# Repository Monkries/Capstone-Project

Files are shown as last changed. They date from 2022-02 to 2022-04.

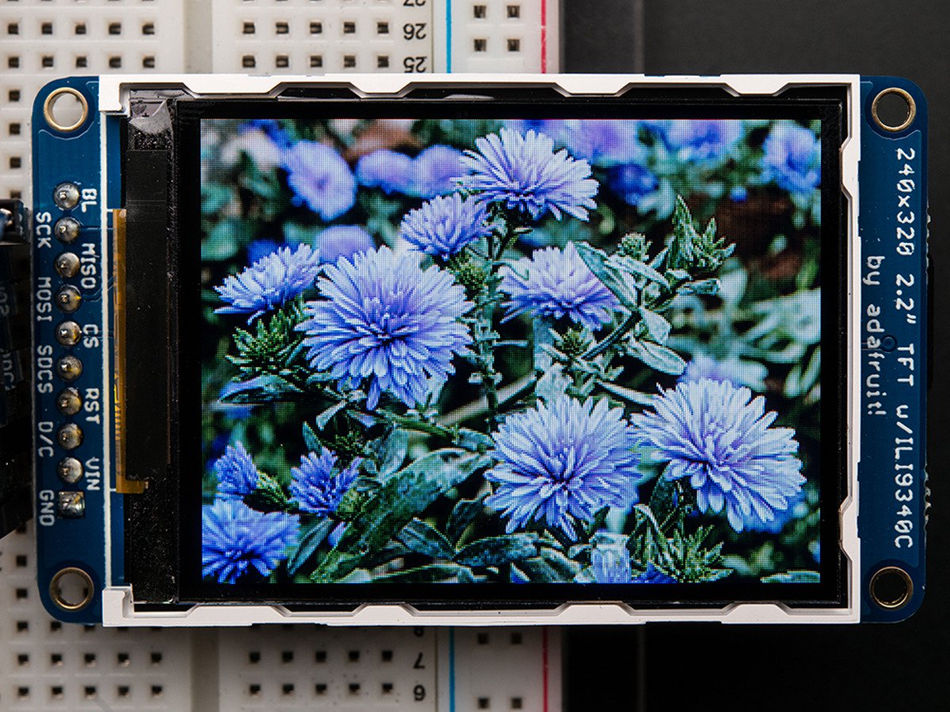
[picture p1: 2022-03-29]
Hardware/footprints/Adafruit-2.2-SPI-TFT-master/assets/image.jpg

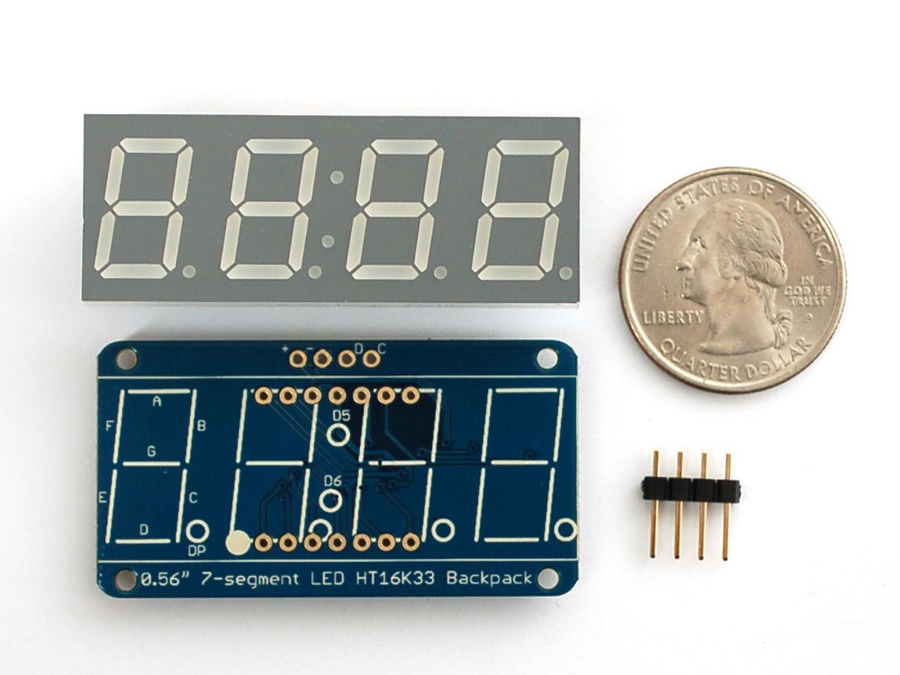
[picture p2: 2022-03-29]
Hardware/footprints/Adafruit-LED-Backpacks-master/assets/881.jpg

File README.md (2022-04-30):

# Capstone-Project
The lathe is arguably the most important machine tool in engineering history, and one of its defining features is the ability to cut threads. For hundreds of years, this has been accomplished by using gears to link the movement of the cutting tool to the movement of the spinning workpiece. To cut finer or coarser threads, the machinist must vary this gear ratio.This system works, but it has limitations. It is poorly suited for small benchtop machines, because the gearbox parts end up extremely small and expensive to manufacture. It is also inconvenient to adjust; the machinist must read a chart and physically add and remove gears from the geartrain. On larger lathes, this inconvenience is reduced using a simple transmission, allowing the machinist to shift several levers according to a chart, but this is more expensive, and more difficult to scale down to smaller machines.This project aims to replace this gearbox with electronics. This will eliminate the need to physically move gears around to adjust the system; instead, machinists will simply type in the desiredthread pitch into the control panel. Additionally, this system will be much more cost-effective and accessible on small benchtop lathes, where the traditional gearbox approach is impractical.

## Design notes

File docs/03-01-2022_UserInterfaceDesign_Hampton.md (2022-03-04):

### Layout

This is just a rough layout, not to scale, and not accounting for font size.

To the left, I've indicated the physical device that corresponds to each area of the screen.

```
{MODE NAME}      | 
                 |
{FEED or PITCH}  | --- Encoder
                 |
{UNITS TOGGLE}   | --- Button
{OTHER SETTING}  | --- Button
{OTHER SETTING}  | --- Button
```

### Mode 1: Threading

Example of cutting an English right-hand thread, with "Hardinge mode" (Rapid right) enabled
```
    THREADING    | 
                 |
      20TPI      | --- Encoder
                 |
      mm/in      | --- Button  (This changes the line above between TPI and mm, for inch or metric threads, respectively)
   RAPID RIGHT   | --- Button  (Options are RAPID RIGHT, RAPID LEFT, RAPID OFF)
                 | --- Button
```

Example of cutting a metric thread, with "Hardinge mode" disabled (no rapids in either direction)
```
    THREADING    | 
                 |
      1.75mm     | --- Encoder
                 |
      mm/in      | --- Button  (This changes the line above between TPI and mm, for inch or metric threads, respectively)
    RAPID OFF    | --- Button  (Options are RAPID RIGHT, RAPID LEFT, RAPID OFF)
                 | --- Button
```

### Mode 2: Power Feed

Example of power feed in inches per revolution
```
  Z POWER FEED   | 
                 |
   0.001"/REV    | --- Encoder
                 |
      mm/in      | --- Button  (This changes the line above between X"/REV and Xmm/REV)
                 | --- Button
                 | --- Button
```

Example of power feed in mm per revolution
```
  Z POWER FEED   | 
                 |
    0.2mm/REV    | --- Encoder
                 |
      mm/in      | --- Button  (This changes the line above between X"/REV and Xmm/REV)
                 | --- Button
                 | --- Button
```

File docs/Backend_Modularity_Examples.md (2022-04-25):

This example shows how the calls that might be made to take two passes on a 13TPI thread.

First we set up the gearbox, then engage the forward feed, allowing the cutter to make its first pass.

Then (whenever the cutter gets to the end of the part, probably triggered by a user input) we disengage the clutch, and engage the reverse feed.

After allowing the cutter to return to the right end of the part, we engage the forward feed again to begin another cutting pass. There's no need to worry about synchronization in software or with a threading dial, the software clutch model takes care of it.
```cpp
  // Example 1: Cutting a 13TPI thread
  els.gearbox.configuredPitch = {13, tpi, rightHandThread_feedLeft}; // Set desired thread pitch
  els.gearbox.enableMotorBraking = true;
  // Start feeding toward the headstock
  els.clutch.engageForward(); 
  // Then return to the start for another pass
  els.clutch.disengage();
  els.clutch.engageReverse();
  els.clutch.disengage();
  // Take another pass (the system will maintain sync automatically)
  els.clutch.engageForward();
 ```
 
 Another example: Configuring the gearbox for an inch power feed rate, feeding 0.005" per revolution of the spindle.
 ```cpp
 
  // Example 2: Power Feeding 0.005" per revolution towards the headstock
  els.gearbox.configuredPitch = {0.005, in_per_rev, rightHandThread_feedLeft};
  els.gearbox.enableMotorBraking = true;
  els.clutch.engageForward();
```

Another example: Configuring the gearbox for a metric thread, 1.75mm pitch.

```cpp

  // Example 3: Cutting a metric 1.75mm pitch thread
  els.gearbox.configuredPitch = {1.75, mm, rightHandThread_feedLeft};
  els.clutch.engageForward();
```

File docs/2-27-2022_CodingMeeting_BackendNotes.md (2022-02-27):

From meeting on 2-27 with Karson and Hampton

```c++

  // Scenario 1: Thread, Hardinge Mode, 1/2"-13
  // Step 1: gearbox setup (from control panel)
  ELS.configureGearing(13, "tpi");
  ELS.configureClutch(false, true, cfg_rapidStepRate);
  ELS.configureMotorBraking(true); // TODO: get from cpanel switch
  // Step 2: Feed lever input
  int feedLeverPosition = 0; //temporary stand-in for cpanel
  if (feedLeverPosition == 1) {
    // If feed lever is in the LEFT position
    ELS.engageZFeedLeft();
  }
  else if (feedLeverPosition == -1) {
    // If feed lever is in the RIGHT position
    ELS.engageZFeedRight();
  }
  else {
    // If feed lever is in the center OFF position
    ELS.disengageZFeed();
  }
  // Step 3: Cycle the backend
  ELS.cycle();
  // Step 3b: Update RPM display
  cPanel.displayRPM(ELS.getSpindleRPM());

  // Scenario 2: Power Feed at 0.003" per revolution
  // Step 1: Gearbox setup
  ELS.configureGearing(0.003, "in/rev");
  ELS.configureClutch(false, false, cfg_rapidStepRate);
  ELS.configureMotorBraking(true);
  // Step 2: Feed lever input
    int feedLeverPosition = 0; //temporary stand-in for cpanel
  if (feedLeverPosition == 1) {
    // If feed lever is in the LEFT position
    ELS.engageZFeedLeft();
  }
  else if (feedLeverPosition == -1) {
    // If feed lever is in the RIGHT position
    ELS.engageZFeedRight();
  }
  else {
    // If feed lever is in the center OFF position
    ELS.disengageZFeed();
  }
  // Step 3: Cycle backend
  ELS.cycle();
  // Step 3b: Update RPM display
  cPanel.displayRPM(ELS.getSpindleRPM());

  ```

  Notes on sync handling:
  
  ```c++
  
  // Measure leadscrew position as an angle from 0 to 2000 steps per revolution
  // Whenever feed is disengaged, call that leadscrew position 0
  // Continuously keep track of hypothetical leadscrew position relative to 0
  // When feed is re-engaged, wait until hypothetical leadscrew position matches 0 position, then start motor
  
  int hypotheticalLeadscrewPosition; // measured in motor steps, relative to real leadscrew position (our zero point)
  int zFeedDirection; // 0=off, 1=right, -1=left
  int zFeedDirection_previousCycle; // Same variable as above, but value from 1 cycle before
  
  bool waitingForClutch;
  
  ```

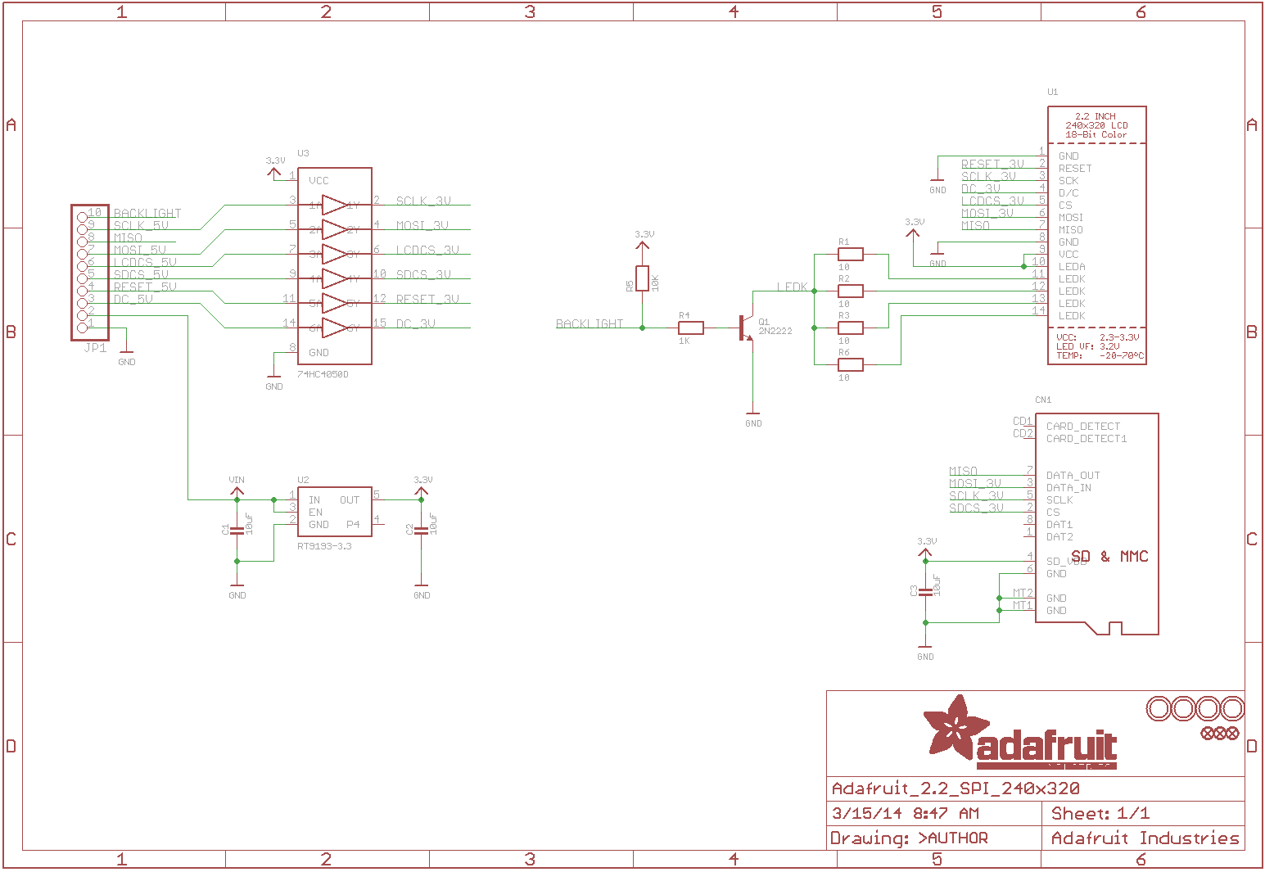
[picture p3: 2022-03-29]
Hardware/footprints/Adafruit-2.2-SPI-TFT-master/Adafruit_2.2_SPI_240x320.png

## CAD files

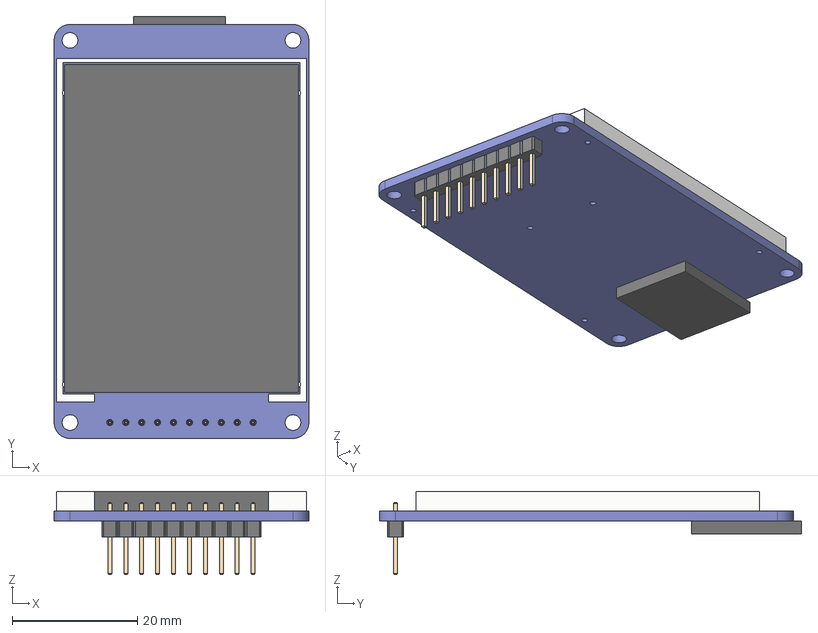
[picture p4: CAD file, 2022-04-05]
Hardware/footprints/Adafruit-2.2-SPI-TFT-master/kicadProject/AdafruitTFT_withHeaders_full3Dmodel.step
40.6 x 67.3 x 13.3 mm
Adafruit_2.2_SPI_240x320 PCB
PinHeader_1x10_P2.54mm_Vertical
LCD
Bezel
MicroSD Card

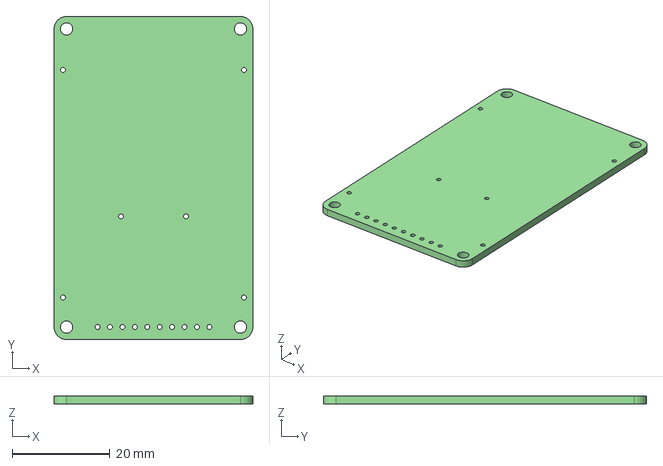
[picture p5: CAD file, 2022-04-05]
Hardware/footprints/Adafruit-2.2-SPI-TFT-master/kicadProject/Adafruit_2.2_SPI_240x320.step
40.6 x 66.0 x 1.60 mm

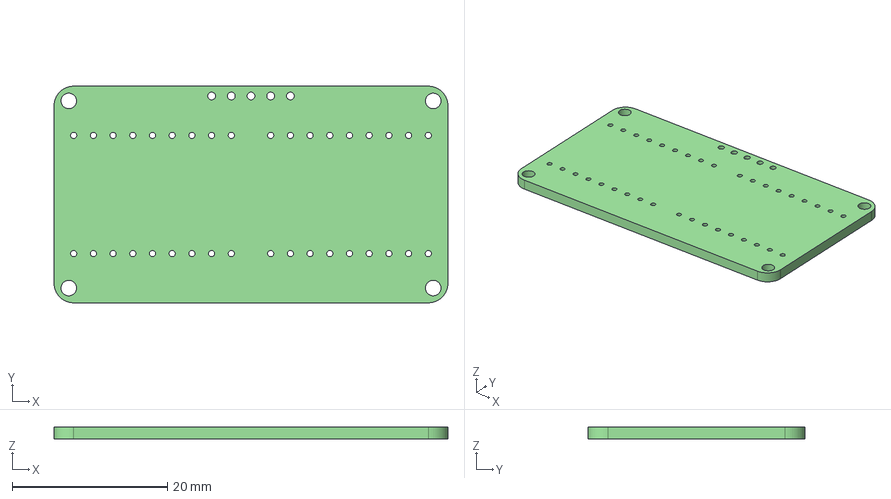
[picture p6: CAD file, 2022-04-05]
Hardware/footprints/Adafruit-LED-Backpacks-master/kicadConversion/Adafruit 0.54 Alphanumeric v0.1.step
50.8 x 27.9 x 1.60 mm

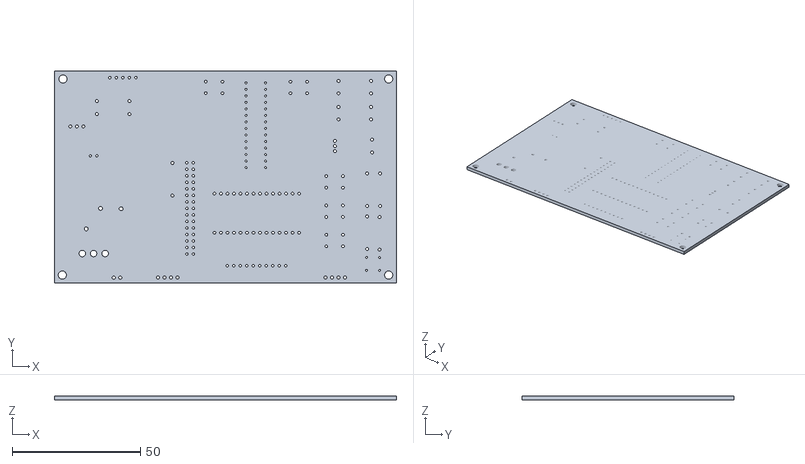
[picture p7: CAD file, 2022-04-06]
Hardware/gerbers/isolatedPCB_version1_3dPrintForAlignment.stl
133.4 x 82.6 x 1.60

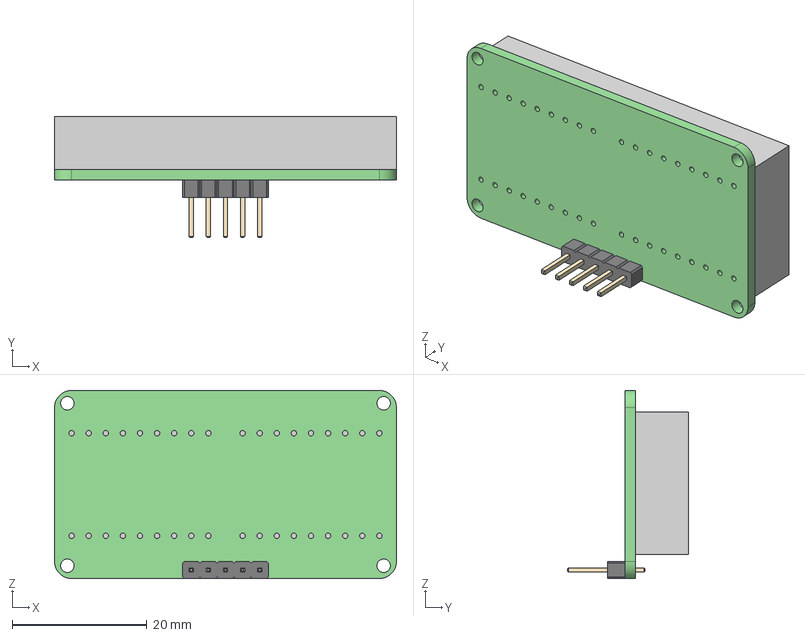
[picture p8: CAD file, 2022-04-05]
Hardware/footprints/Adafruit-LED-Backpacks-master/kicadConversion/Adafruit_Alphanumeric_WithHeadersAndComponents v4.step
50.8 x 18.0 x 27.9 mm
_autosave-Adafruit 0.54 Alphanumeric v0.1 PCB
PinHeader_1x05_P2.54mm_Vertical
DisplayModules

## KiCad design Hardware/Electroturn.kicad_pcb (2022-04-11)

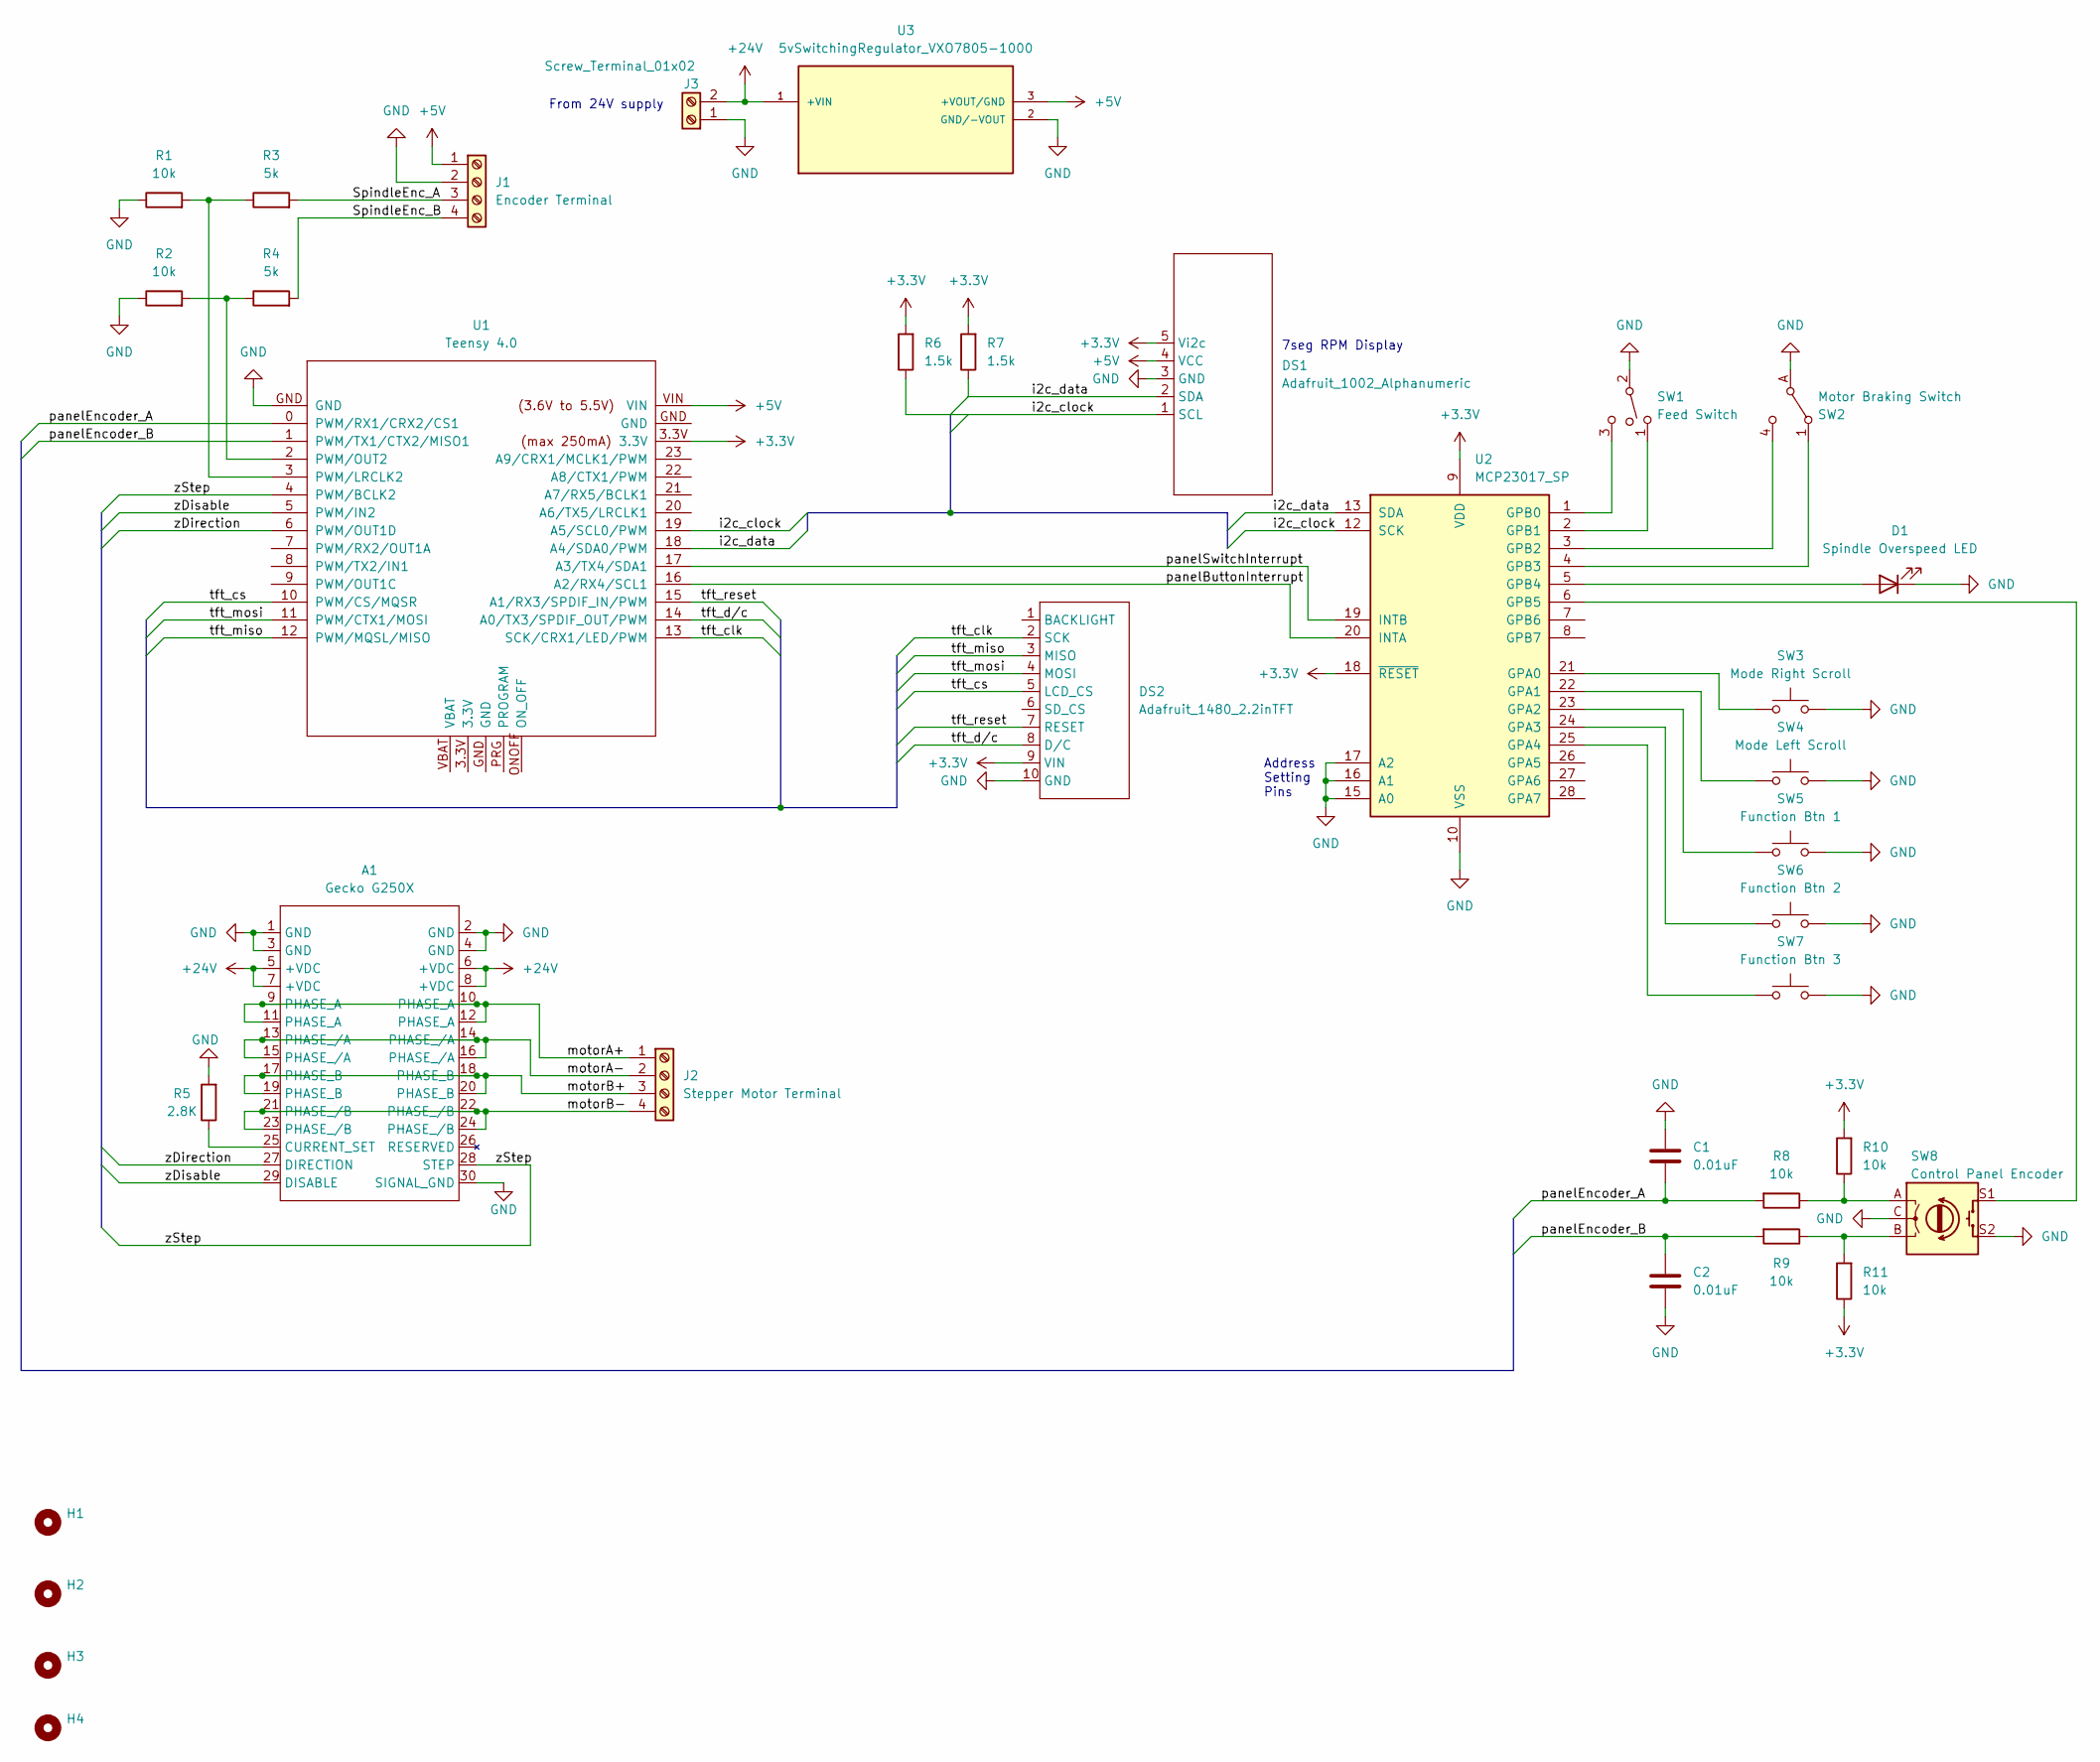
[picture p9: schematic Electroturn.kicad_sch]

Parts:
A1: Gecko G250X; GeckoG250XR2_WithHeatsink
C1, C2: 0.01uF; C_Disc_D6.0mm_W2.5mm_P5.00mm
D1: Spindle Overspeed LED; LED_D5.0mm
DS1: Adafruit_1002_Alphanumeric; Adafruit1002_0.54inAlphanumericBackpack
DS2: Adafruit_1480_2.2inTFT; Adafruit1480_TFTwithHeaders
H1, H2, H3, H4: (no value)
J1: Encoder Terminal; ScrewTerminal4_OSTVN04A150
J2: Stepper Motor Terminal; ScrewTerminal4_OSTVN04A150
J3: Screw_Terminal_01x02; 01x02ScrewTerm_OSTVN02A150
R1, R2, R8, R9, R10, R11: 10k; R_Axial_DIN0411_L9.9mm_D3.6mm_P12.70mm_Horizontal
R3, R4: 5k; R_Axial_DIN0411_L9.9mm_D3.6mm_P12.70mm_Horizontal
R5: 2.8K; R_Axial_DIN0411_L9.9mm_D3.6mm_P12.70mm_Horizontal
R6, R7: 1.5k; R_Axial_DIN0411_L9.9mm_D3.6mm_P12.70mm_Horizontal
SW1: Feed Switch; SPDT_OnOffOn_ToggleSwitch_fromECEdepartment_CircularPads
SW2: Motor Braking Switch; SW_SPDT_CK_ A11405RNZQ
SW3: Mode Right Scroll; SW_PUSH_6mm_H9.5mm
SW4: Mode Left Scroll; SW_PUSH_6mm_H9.5mm
SW5: Function Btn 1; SW_PUSH_6mm_H9.5mm
SW6: Function Btn 2; SW_PUSH_6mm_H9.5mm
SW7: Function Btn 3; SW_PUSH_6mm_H9.5mm
SW8: Control Panel Encoder; CUIDevices_ACZ11BR1E20FD112C
U1: Teensy 4.0; Teensy40_OnFemaleHeaders
U2: MCP23017_SP; DIP-28_W7.62mm
U3: 5vSwitchingRegulator_VXO7805-1000; 5vSwitchingRegulator_CONV_VXO7805-1000; PARTREV 1.0

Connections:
+3V3: DS1.5 (Vi2c), DS2.9 (VIN), R6.2, R7.2, R10.2, R11.1, U1.3.3V, U2.9 (VDD), U2.18 (~RESET)
+5V: DS1.4 (VCC), J1.1, U1.VIN, U3.3 (+VOUT/GND)
+24V: A1.5 (+VDC), A1.6 (+VDC), A1.7 (+VDC), A1.8 (+VDC), J3.2, U3.1 (+VIN)
/SpindleEnc_A: J1.3, R3.2
/SpindleEnc_B: J1.4, R4.2
/i2c_clock: DS1.1 (SCL), R6.1, U1.19 (A5/SCL0/PWM), U2.12 (SCK)
/i2c_data: DS1.2 (SDA), R7.1, U1.18 (A4/SDA0/PWM), U2.13 (SDA)
/motorA+: A1.9 (PHASE_A), A1.10 (PHASE_A), A1.11 (PHASE_A), A1.12 (PHASE_A), J2.1
/motorA-: A1.13 (PHASE_/A), A1.14 (PHASE_/A), A1.15 (PHASE_/A), A1.16 (PHASE_/A), J2.2
/motorB+: A1.17 (PHASE_B), A1.18 (PHASE_B), A1.19 (PHASE_B), A1.20 (PHASE_B), J2.3
/motorB-: A1.21 (PHASE_/B), A1.22 (PHASE_/B), A1.23 (PHASE_/B), A1.24 (PHASE_/B), J2.4
/panelButtonInterrupt: U1.16 (A2/RX4/SCL1), U2.20 (INTA)
/panelEncoder_A: C1.2, R8.2, U1.0 (PWM/RX1/CRX2/CS1)
/panelEncoder_B: C2.1, R9.2, U1.1 (PWM/TX1/CTX2/MISO1)
/panelSwitchInterrupt: U1.17 (A3/TX4/SDA1), U2.19 (INTB)
/tft_clk: DS2.2 (SCK), U1.13 (SCK/CRX1/LED/PWM)
/tft_cs: DS2.5 (LCD_CS), U1.10 (PWM/CS/MQSR)
/tft_d/c: DS2.8 (D/C), U1.14 (A0/TX3/SPDIF_OUT/PWM)
/tft_miso: DS2.3 (MISO), U1.12 (PWM/MQSL/MISO)
/tft_mosi: DS2.4 (MOSI), U1.11 (PWM/CTX1/MOSI)
/tft_reset: DS2.7 (RESET), U1.15 (A1/RX3/SPDIF_IN/PWM)
/zDirection: A1.27 (DIRECTION), U1.6 (PWM/OUT1D)
/zDisable: A1.29 (DISABLE), U1.5 (PWM/IN2)
/zStep: A1.28 (STEP), U1.4 (PWM/BCLK2)
GND: A1.1 (GND), A1.2 (GND), A1.3 (GND), A1.4 (GND), A1.30 (SIGNAL_GND), C1.1, C2.2, D1.1 (K), DS1.3 (GND), DS2.10 (GND), J1.2, J3.1, R1.1, R2.1, R5.2, SW1.2, SW2.A, SW3.2, SW4.2, SW5.2, SW6.2, SW7.2, SW8.C, SW8.S2, U1.GND, U2.10 (VSS), U2.15 (A0), U2.16 (A1), U2.17 (A2), U3.2 (GND/-VOUT)
unnamed: A1.25 (CURRENT_SET), R5.1
unnamed: D1.2 (A), U2.5 (GPB4)
unnamed: R1.2, R3.1, U1.3 (PWM/LRCLK2)
unnamed: R2.2, R4.1, U1.2 (PWM/OUT2)
unnamed: R8.1, R10.1, SW8.A
unnamed: R9.1, R11.2, SW8.B
unnamed: SW1.1, U2.2 (GPB1)
unnamed: SW1.3, U2.1 (GPB0)
unnamed: SW2.1, U2.4 (GPB3)
unnamed: SW2.4, U2.3 (GPB2)
unnamed: SW3.1, U2.21 (GPA0)
unnamed: SW4.1, U2.22 (GPA1)
unnamed: SW5.1, U2.23 (GPA2)
unnamed: SW6.1, U2.24 (GPA3)
unnamed: SW7.1, U2.25 (GPA4)
unnamed: SW8.S1, U2.6 (GPB5)

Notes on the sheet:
7seg RPM Display
From 24V supply
Address Setting Pins

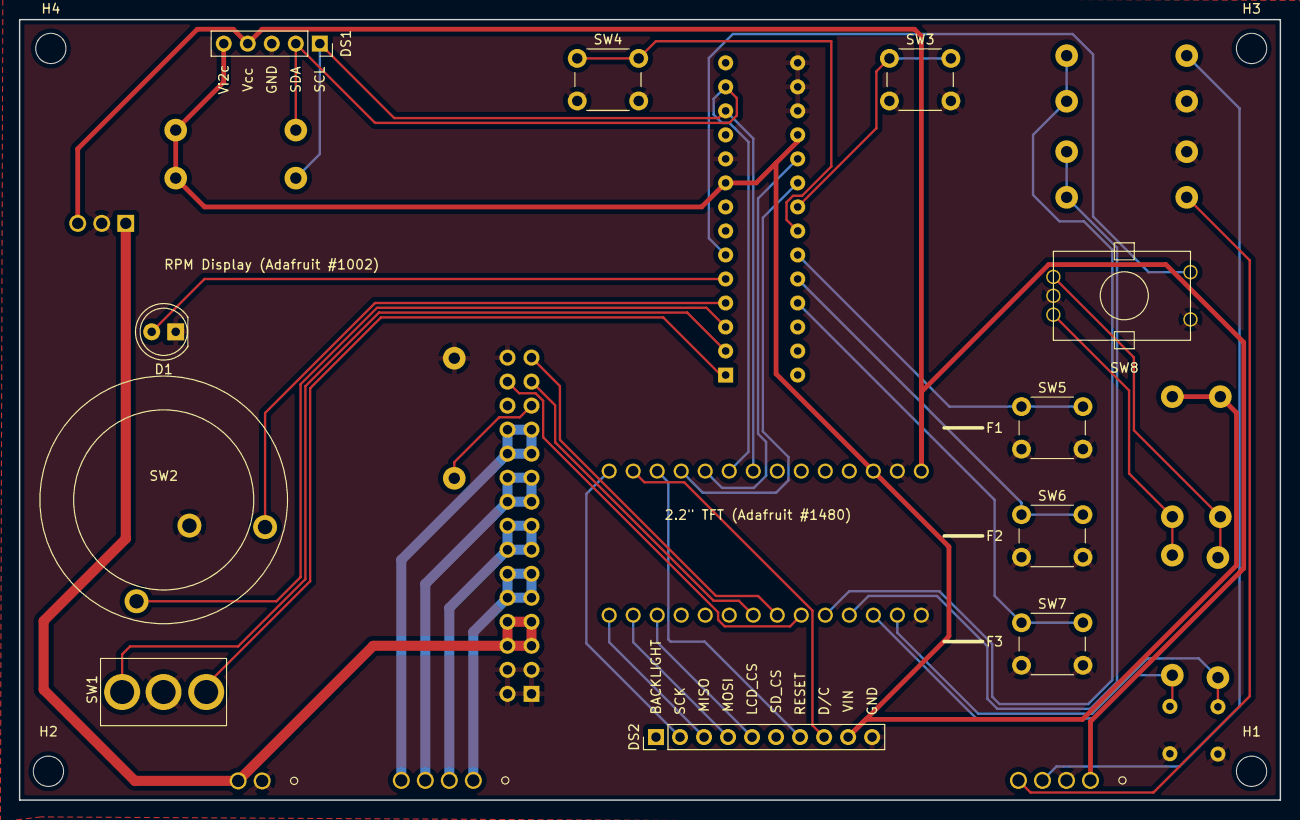
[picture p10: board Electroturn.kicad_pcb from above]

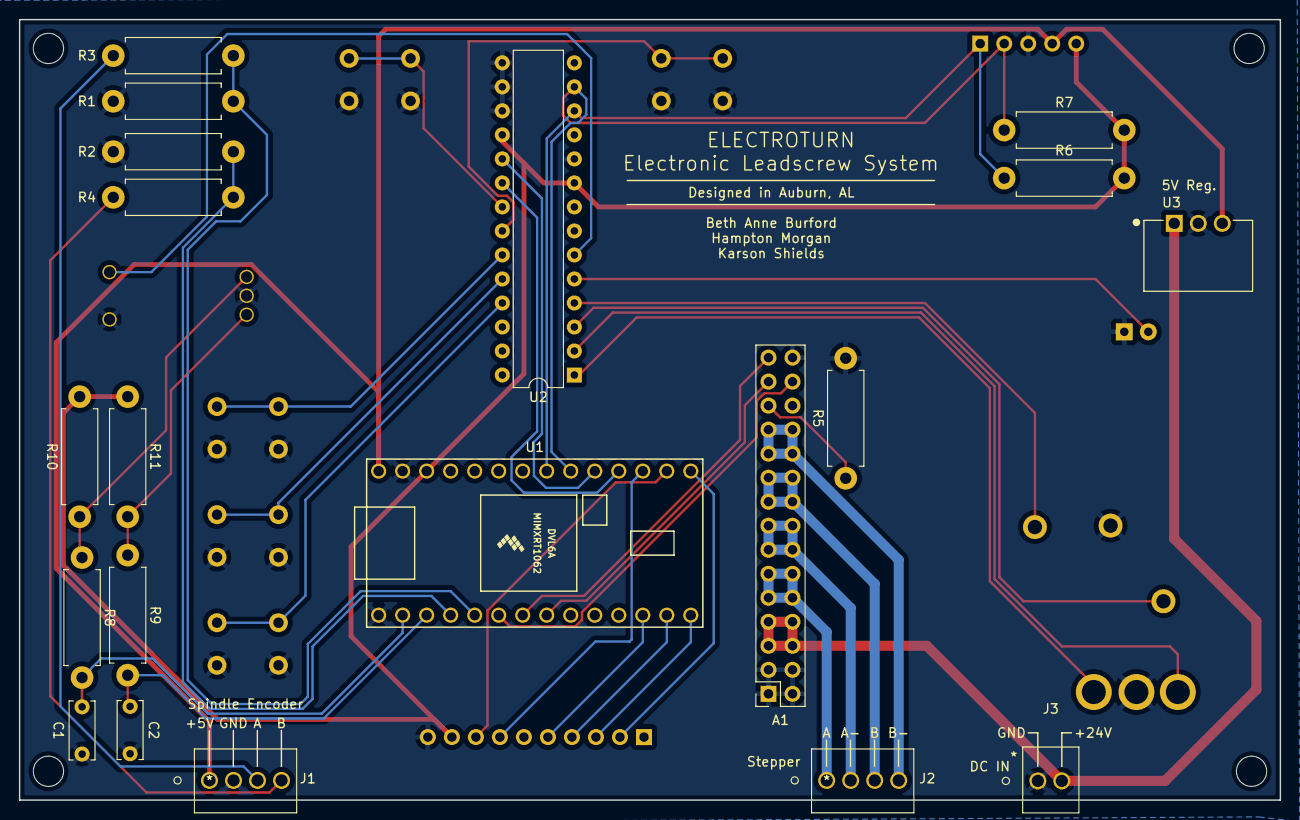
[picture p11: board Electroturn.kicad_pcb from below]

Board: 2 copper layers, 133.4 x 82.5 mm, 35 parts (20 on the bottom side), 41 nets.

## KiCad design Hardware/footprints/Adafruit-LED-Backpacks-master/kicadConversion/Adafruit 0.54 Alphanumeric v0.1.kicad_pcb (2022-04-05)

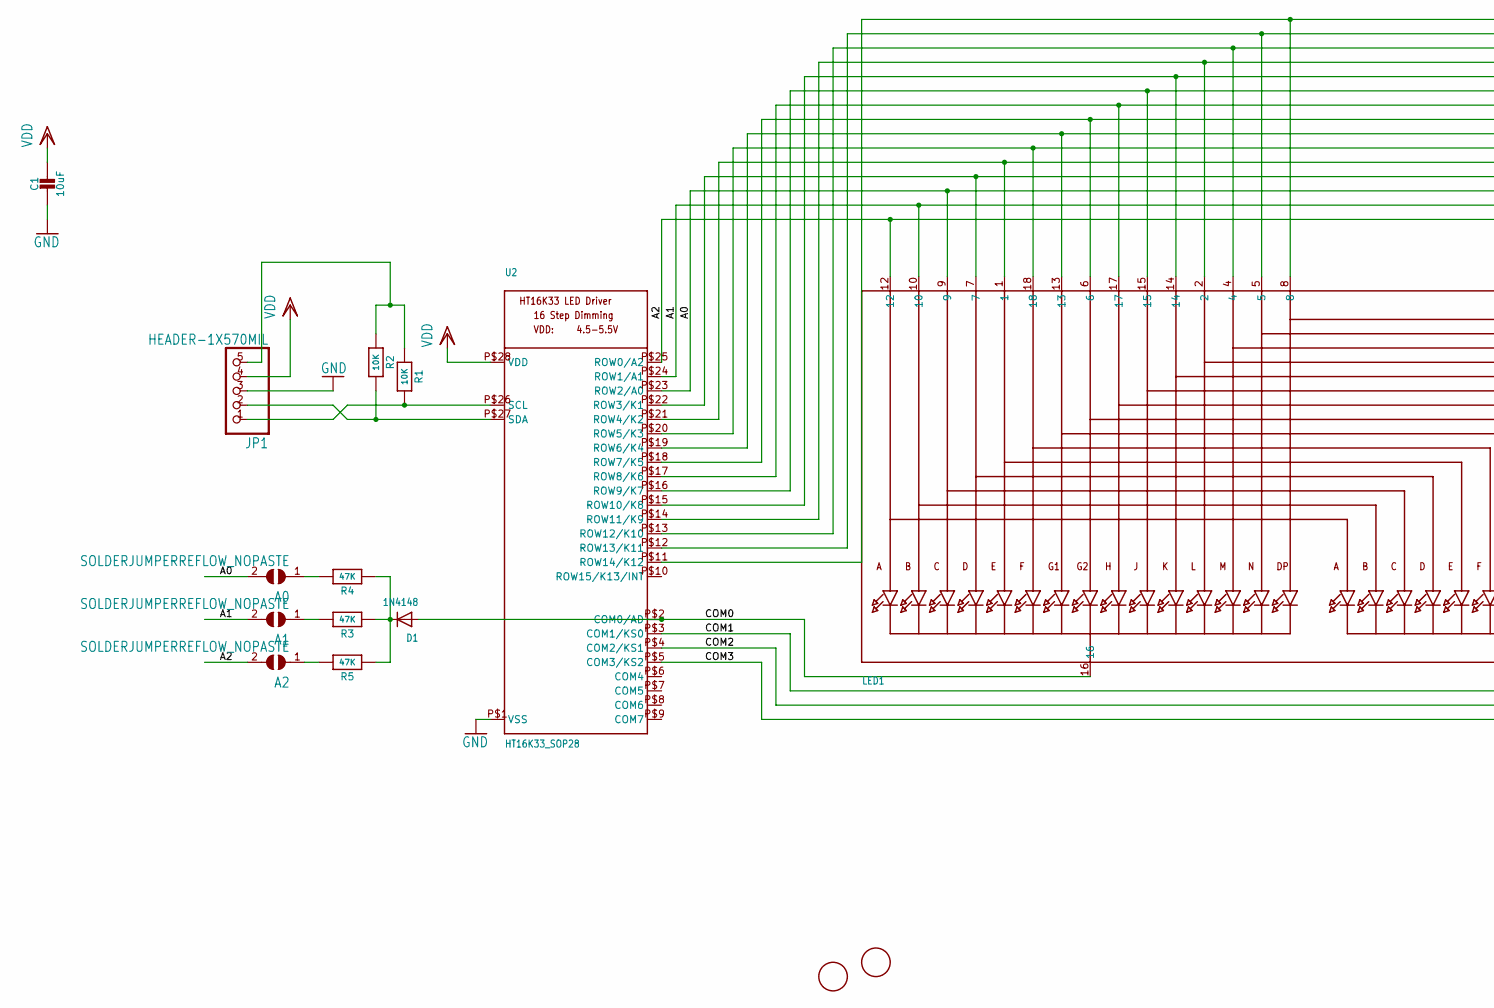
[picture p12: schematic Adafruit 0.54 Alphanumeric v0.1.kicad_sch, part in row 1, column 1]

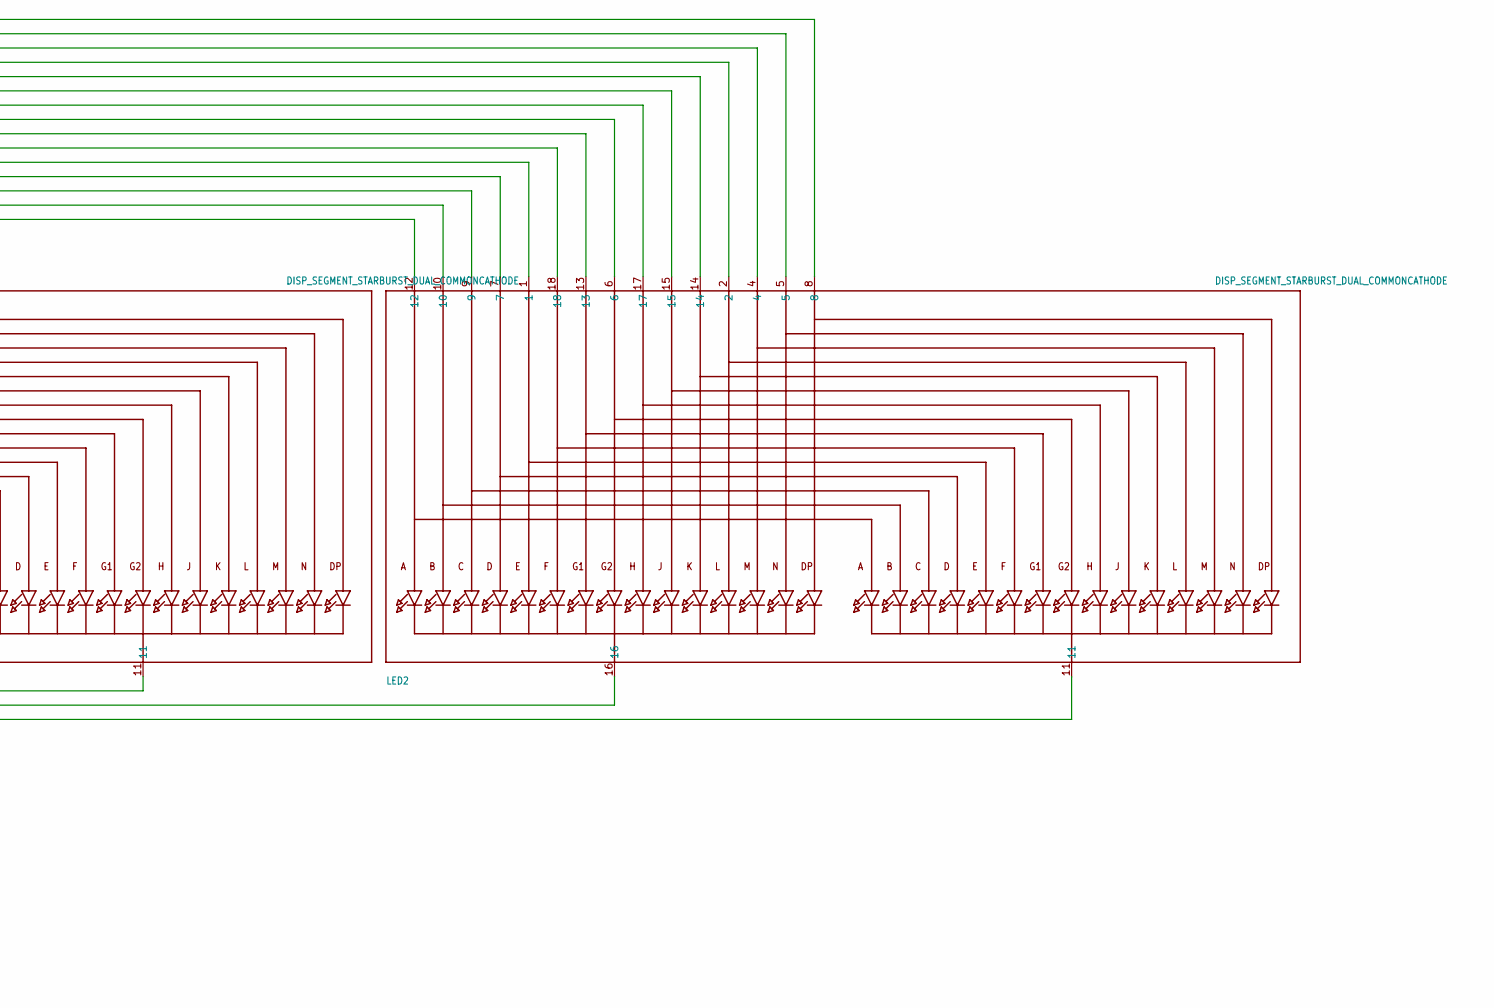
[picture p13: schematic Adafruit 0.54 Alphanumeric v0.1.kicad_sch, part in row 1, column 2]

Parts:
A0, A1, A2: SOLDERJUMPERREFLOW_NOPASTE; SOLDERJUMPER_REFLOW_NOPASTE
C1: 10uF; 0805-NO
D1: 1N4148; SOD-323F
JP1: HEADER-1X570MIL; 1X05_ROUND_70
LED1, LED2: DISP_SEGMENT_STARBURST_DUAL_COMMONCATHODE; SEGMENT_STARTBUST_DUAL_KWA-541CBB
R1, R2: 10K; 0805-NO
R3, R4, R5: 47K; 0805-NO
U2: HT16K33_SOP28; SOP28_300MIL
U$1, U$2: FIDUCIAL; FIDUCIAL_1MM

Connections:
A0: A0.2, LED1.9, LED2.9, U2.P$23 (ROW2/A0)
A1: A1.2, LED1.10, LED2.10, U2.P$24 (ROW1/A1)
A2: A2.2, LED1.12, LED2.12, U2.P$25 (ROW0/A2)
COM0: D1.A, LED1.16, U2.P$2 (COM0/AD)
COM1: LED1.11, U2.P$3 (COM1/KS0)
COM2: LED2.16, U2.P$4 (COM2/KS1)
COM3: LED2.11, U2.P$5 (COM3/KS2)
GND: C1.2, JP1.3, U2.P$1 (VSS)
unnamed: D1.C, R3.1, R4.1, R5.1
unnamed: JP1.5, R1.1, R2.1
unnamed: LED1.17, LED2.17, U2.P$17 (ROW8/K6)
unnamed: LED1.15, LED2.15, U2.P$16 (ROW9/K7)
unnamed: LED1.14, LED2.14, U2.P$15 (ROW10/K8)
unnamed: A2.1, R5.2
unnamed: LED1.2, LED2.2, U2.P$14 (ROW11/K9)
unnamed: LED1.4, LED2.4, U2.P$13 (ROW12/K10)
unnamed: LED1.7, LED2.7, U2.P$22 (ROW3/K1)
unnamed: LED1.1, LED2.1, U2.P$21 (ROW4/K2)
unnamed: LED1.18, LED2.18, U2.P$20 (ROW5/K3)
unnamed: LED1.13, LED2.13, U2.P$19 (ROW6/K4)
unnamed: LED1.5, LED2.5, U2.P$12 (ROW13/K11)
unnamed: LED1.8, LED2.8, U2.P$11 (ROW14/K12)
unnamed: LED1.6, LED2.6, U2.P$18 (ROW7/K5)
unnamed: A1.1, R3.2
unnamed: A0.1, R4.2
SCL: JP1.1, R1.2, U2.P$26 (SCL)
SDA: JP1.2, R2.2, U2.P$27 (SDA)
VDD: C1.1, JP1.4, U2.P$28 (VDD)

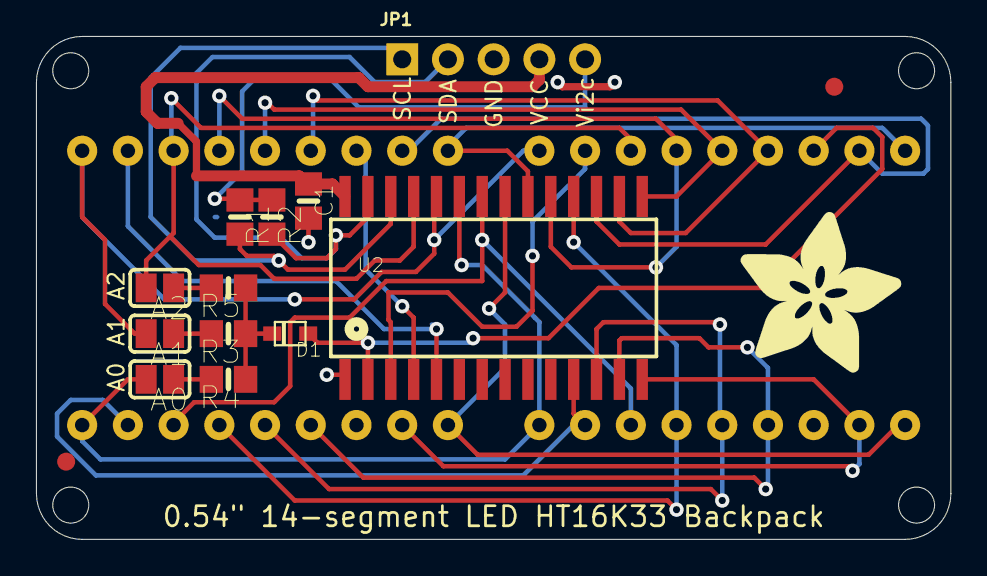
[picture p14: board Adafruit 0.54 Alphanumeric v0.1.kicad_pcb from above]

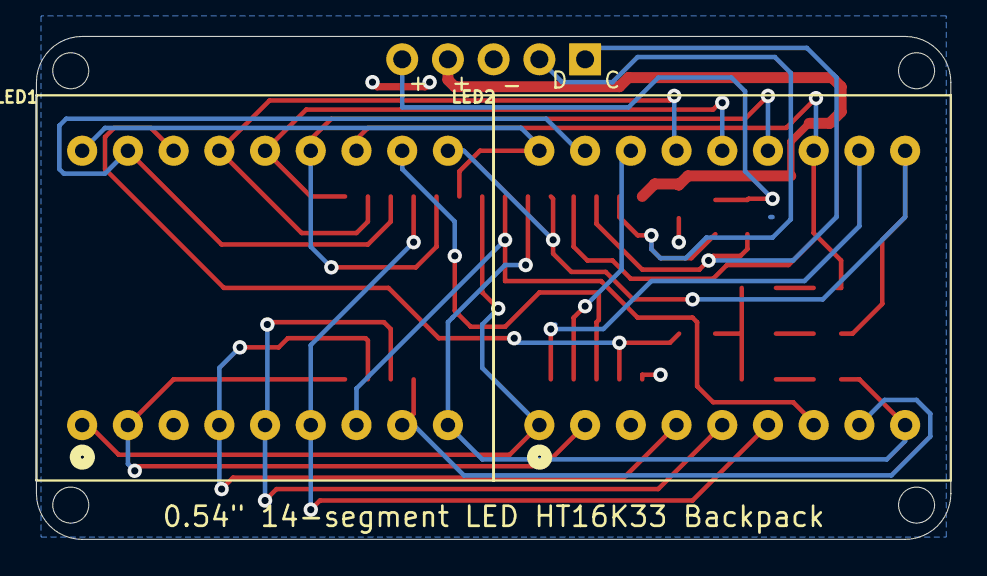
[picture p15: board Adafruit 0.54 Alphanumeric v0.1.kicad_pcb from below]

Board: 16 copper layers, 50.8 x 27.9 mm, 21 parts (2 on the bottom side), 28 nets.

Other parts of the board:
@HOLE0, @HOLE1, @HOLE2, @HOLE3: (no value)
U$3: ADAFRUIT_9MM

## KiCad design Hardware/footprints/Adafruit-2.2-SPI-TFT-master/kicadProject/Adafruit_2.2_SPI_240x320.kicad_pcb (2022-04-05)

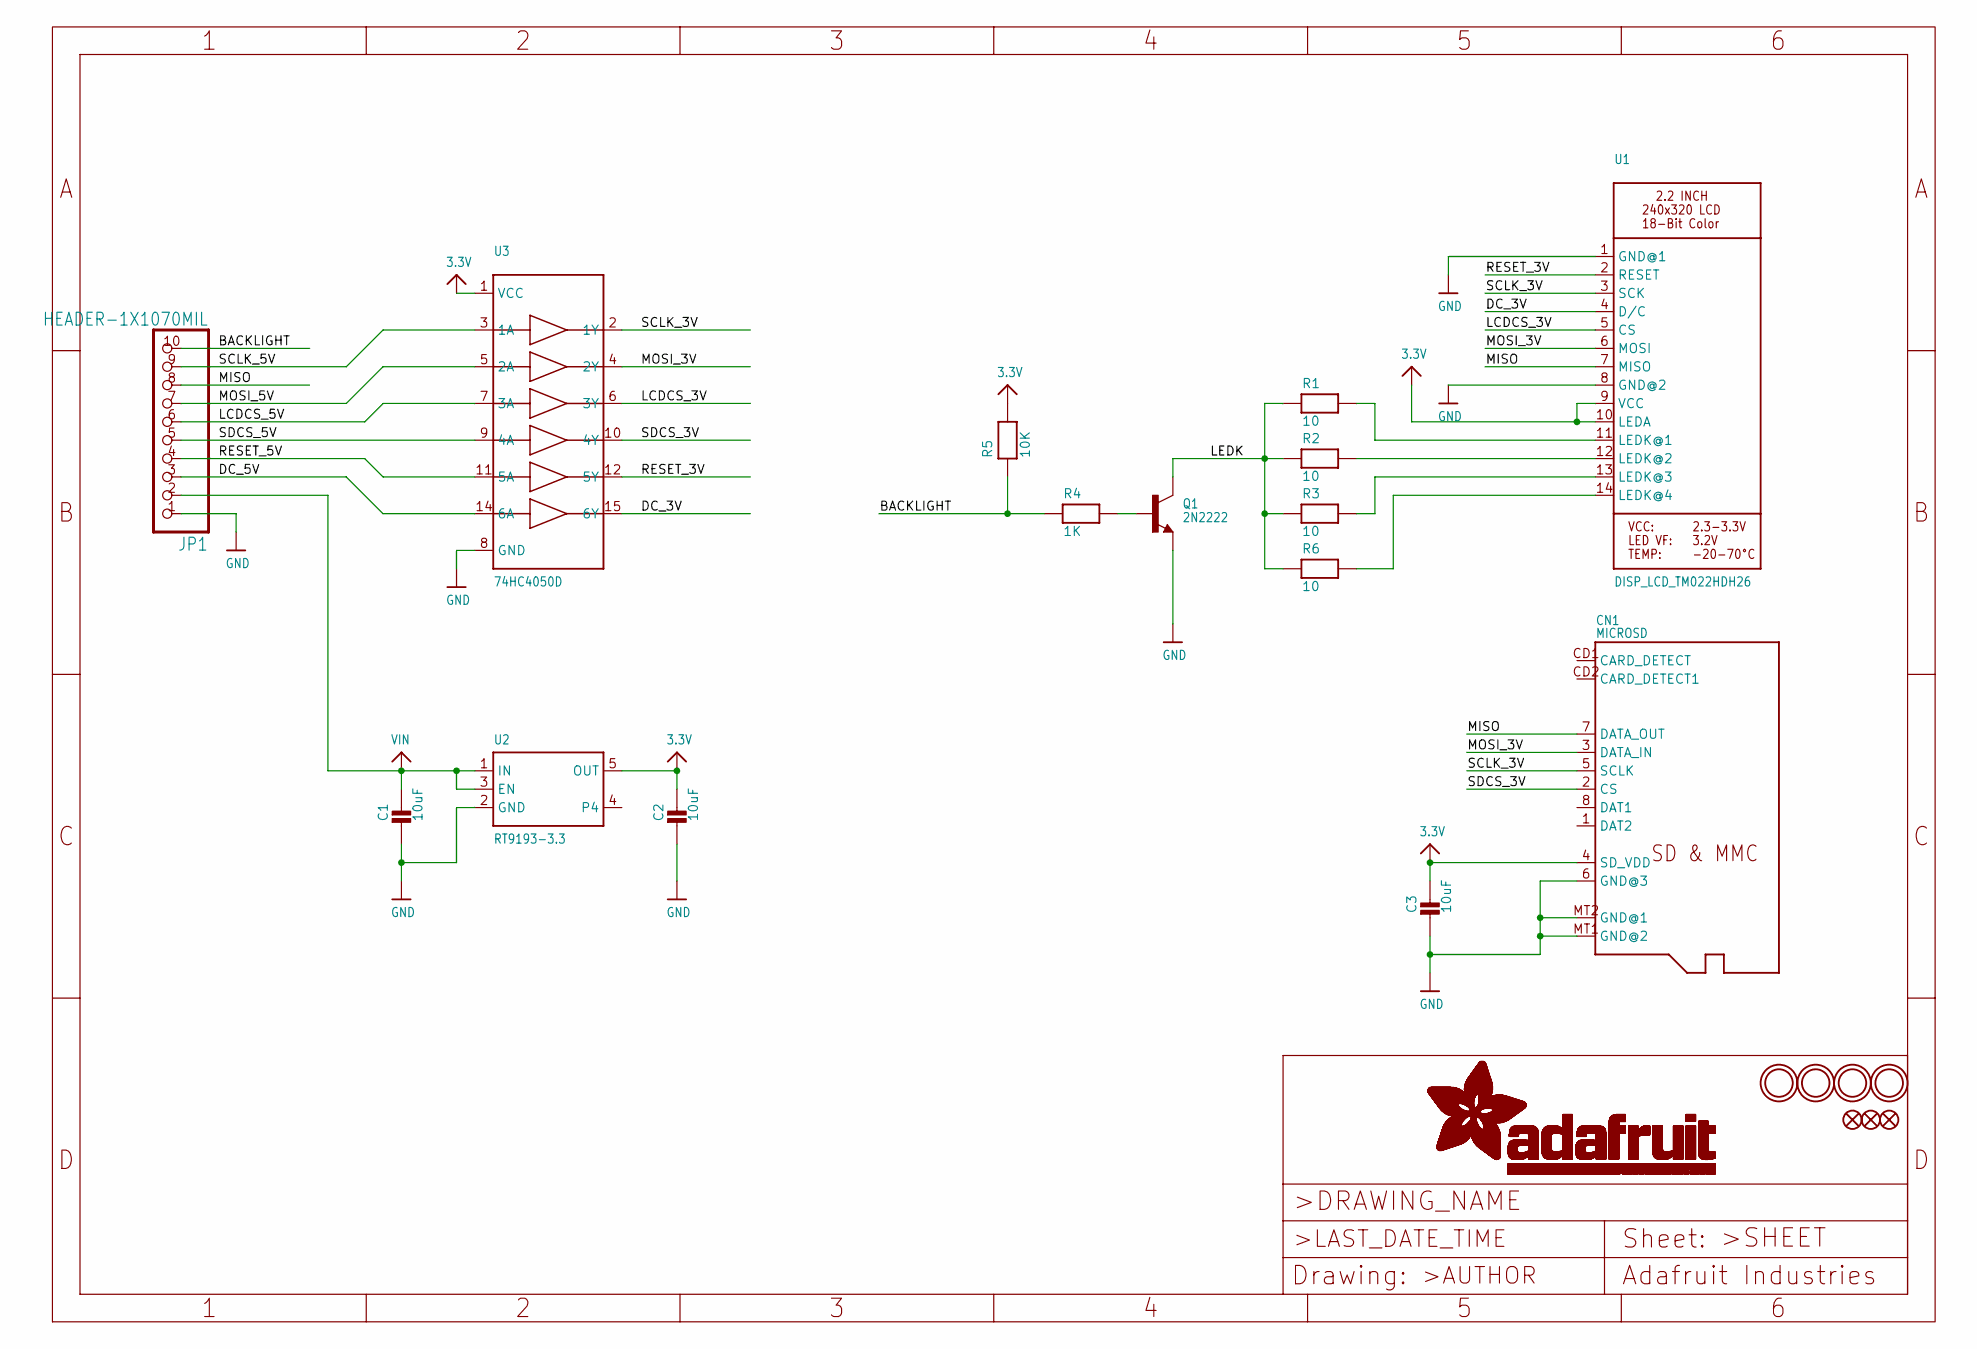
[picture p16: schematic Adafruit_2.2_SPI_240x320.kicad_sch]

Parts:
C1, C2, C3: 10uF; _0805MP
CN1: MICROSD
FID1, FID2: FIDUCIAL""; FIDUCIAL_1MM
FID3: EXCLUDE; FIDUCIAL_1MM
JP1: HEADER-1X1070MIL; 1X10_ROUND70
Q1: 2N2222; SOT23-WIDE
R1, R2, R3, R6: 10; _0805MP
R4: 1K; _0805MP
R5: 10K; _0805MP
U1: DISP_LCD_TM022HDH26; TM022HDH26_2.2IN_LCD
U2: RT9193-3.3; SOT23-5
U3: 74HC4050D; SOIC16
U$2, U$3, U$4, U$5: MOUNTINGHOLE2.5; MOUNTINGHOLE_2.5_PLATED

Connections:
3.3V: C2.1, C3.1, CN1.4 (SD_VDD), R5.2, U1.9 (VCC), U1.10 (LEDA), U2.5 (OUT), U3.1 (VCC)
BACKLIGHT: JP1.10, R4.1, R5.1
DC_3V: U1.4 (D/C), U3.15 (6Y)
DC_5V: JP1.3, U3.14 (6A)
GND: C1.2, C2.2, C3.2, CN1.6 (GND@3), CN1.MT1 (GND@2), CN1.MT2 (GND@1), JP1.1, Q1.2 (E), U1.1 (GND@1), U1.8 (GND@2), U2.2 (GND), U3.8 (GND)
LCDCS_3V: U1.5 (CS), U3.6 (3Y)
LCDCS_5V: JP1.6, U3.7 (3A)
LEDK: Q1.3 (C), R1.1, R2.1, R3.1, R6.1
MISO: CN1.7 (DATA_OUT), JP1.8, U1.7 (MISO)
MOSI_3V: CN1.3 (DATA_IN), U1.6 (MOSI), U3.4 (2Y)
MOSI_5V: JP1.7, U3.5 (2A)
unnamed: R1.2, U1.11 (LEDK@1)
unnamed: R2.2, U1.12 (LEDK@2)
unnamed: R3.2, U1.13 (LEDK@3)
unnamed: Q1.1 (B), R4.2
unnamed: R6.2, U1.14 (LEDK@4)
RESET_3V: U1.2 (RESET), U3.12 (5Y)
RESET_5V: JP1.4, U3.11 (5A)
SCLK_3V: CN1.5 (SCLK), U1.3 (SCK), U3.2 (1Y)
SCLK_5V: JP1.9, U3.3 (1A)
SDCS_3V: CN1.2 (CS), U3.10 (4Y)
SDCS_5V: JP1.5, U3.9 (4A)
VIN: C1.1, JP1.2, U2.1 (IN), U2.3 (EN)

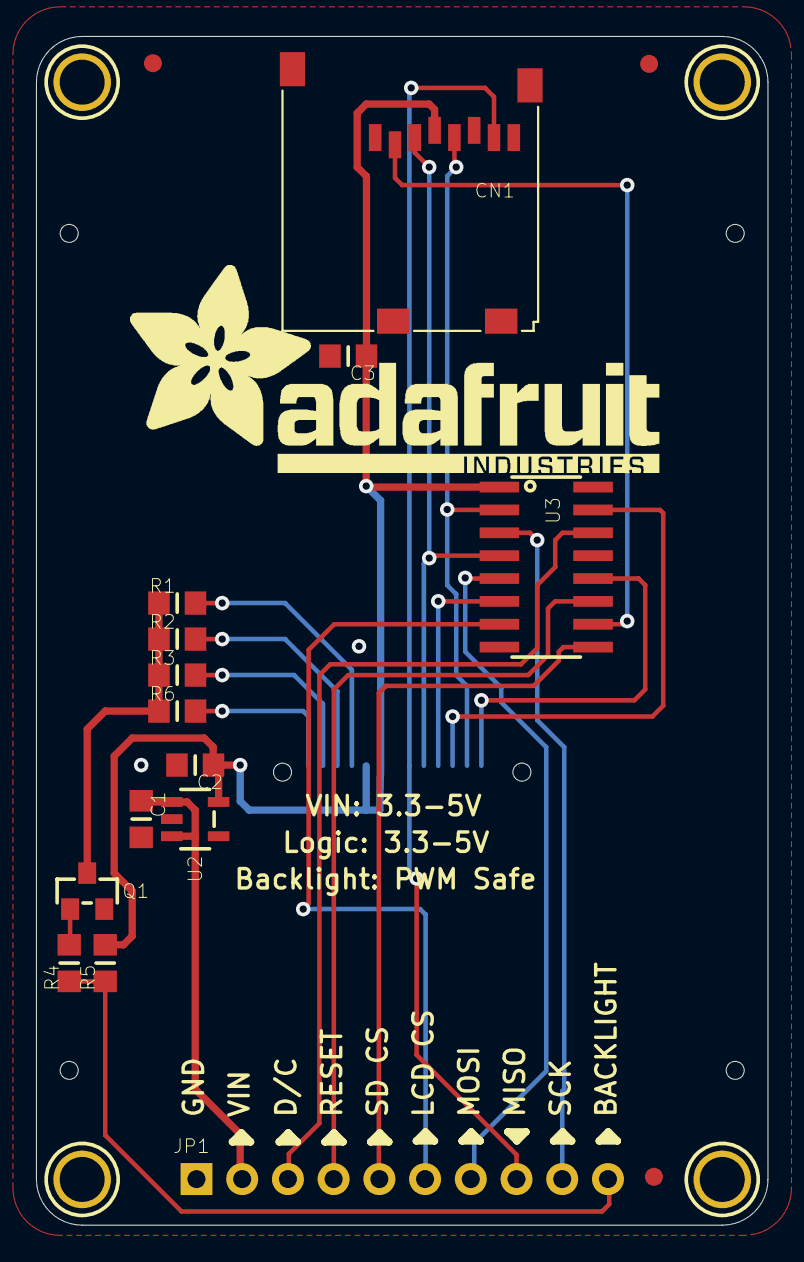
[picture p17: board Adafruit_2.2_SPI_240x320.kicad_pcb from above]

Board: 2 copper layers, 40.6 x 66.0 mm, 23 parts (1 on the bottom side), 23 nets.

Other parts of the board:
U$20: ADAFRUIT_TEXT_30MM

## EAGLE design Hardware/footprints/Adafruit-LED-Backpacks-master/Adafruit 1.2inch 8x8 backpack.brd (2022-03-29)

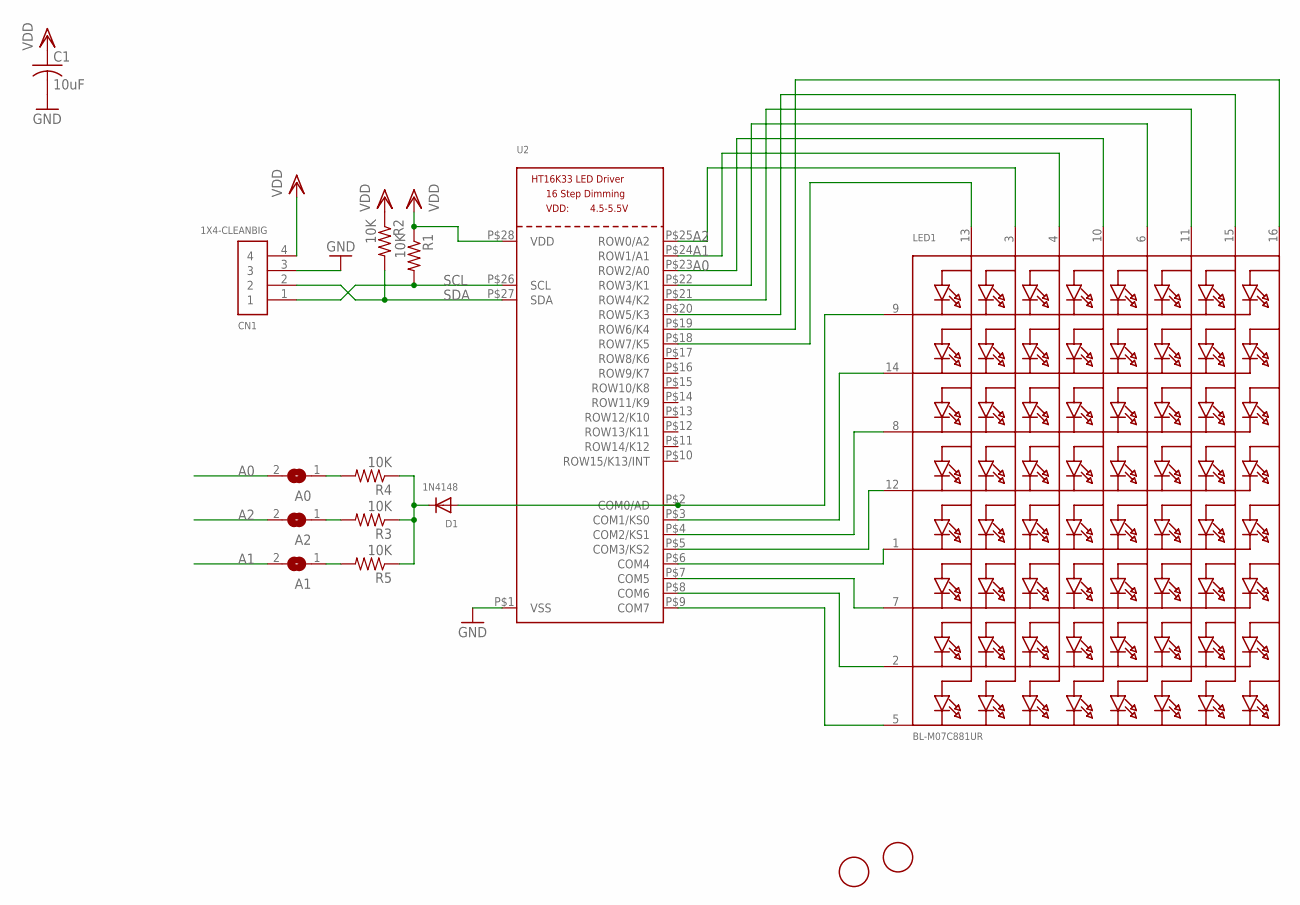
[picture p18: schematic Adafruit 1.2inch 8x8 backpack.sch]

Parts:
A0, A1, A2: SOLDERJUMPERREFLOW_NOPASTE; SOLDERJUMPER_REFLOW_NOPASTE
C1: 10uF; C0805
CN1: 1X4-CLEANBIG; 1X04-CLEANBIG
D1: 1N4148; SOD-323F
LED1: BL-M07C881UR; SEGMENT_BL-M12A881UR
R1, R2, R3, R4, R5: 10K; R0805
U2: HT16K33_SOP28; SOP28_300MIL
U$1, U$2: FIDUCIAL; FIDUCIAL_1MM

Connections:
A0: A0.2, LED1.10 (A4), U2.P$23 (ROW2/A0)
A1: A1.2, LED1.4 (A3), U2.P$24 (ROW1/A1)
A2: A2.2, LED1.3 (A2), U2.P$25 (ROW0/A2)
GND: C1.2, CN1.3, U2.P$1 (VSS)
unnamed: LED1.5 (K8), U2.P$9 (COM7)
unnamed: LED1.2 (K7), U2.P$8 (COM6)
unnamed: LED1.7 (K6), U2.P$7 (COM5)
unnamed: LED1.1 (K5), U2.P$6 (COM4)
unnamed: LED1.12 (K4), U2.P$5 (COM3/KS2)
unnamed: LED1.8 (K3), U2.P$4 (COM2/KS1)
unnamed: LED1.14 (K2), U2.P$3 (COM1/KS0)
unnamed: D1.A, LED1.9 (K1), U2.P$2 (COM0/AD)
unnamed: A1.1, R5.2
unnamed: LED1.6 (A5), U2.P$22 (ROW3/K1)
unnamed: LED1.11 (A6), U2.P$21 (ROW4/K2)
unnamed: D1.C, R3.1, R4.1, R5.1
unnamed: LED1.13 (A1), U2.P$18 (ROW7/K5)
unnamed: A2.1, R3.2
unnamed: A0.1, R4.2
SCL: CN1.1, R1.2, U2.P$26 (SCL)
SDA: CN1.2, R2.2, U2.P$27 (SDA)
SEG_F: LED1.15 (A7), U2.P$20 (ROW5/K3)
SEG_G: LED1.16 (A8), U2.P$19 (ROW6/K4)
VDD: C1.1, CN1.4, R1.1, R2.1, U2.P$28 (VDD)

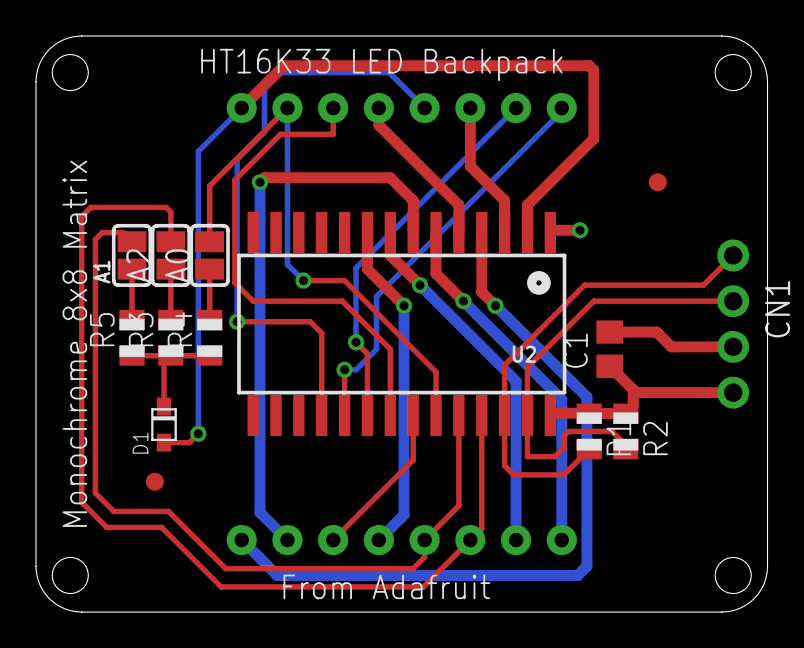
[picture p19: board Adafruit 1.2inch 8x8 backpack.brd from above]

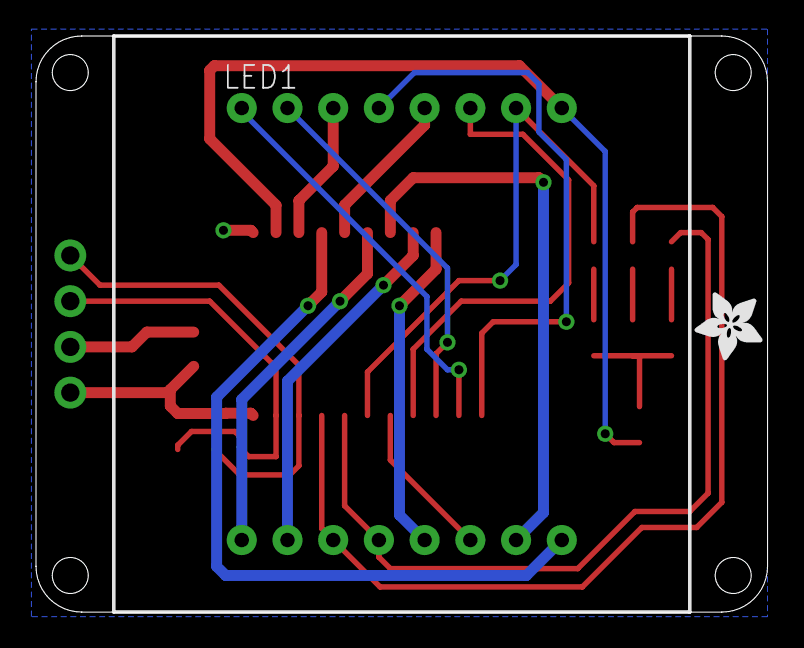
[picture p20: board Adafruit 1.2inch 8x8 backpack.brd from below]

Board: 2 copper layers, 40.6 x 32.0 mm, 16 parts (2 on the bottom side), 24 nets.

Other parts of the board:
U$3: ADAFRUIT_3.5MM

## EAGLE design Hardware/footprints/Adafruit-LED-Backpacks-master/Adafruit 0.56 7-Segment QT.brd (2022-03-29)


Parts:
A0, A1, A2: SOLDERJUMPER; SOLDERJUMPER_ARROW_NOPASTE
C1: 10uF; 0805_10MGAP
CN1: 1X4-CLEANBIG; 1X04-CLEANBIG
CONN1, CONN2: STEMMA_I2C_QTRA; JST_SH4_RA
D1: 1N4148; SOD-323F
D2: GREEN; CHIPLED_0603_NOOUTLINE
D3: DNP; SOD-323F
LED2: DISP_SEGMENT_4DIGIT_BL-Q56C43; SEGMENT-BL-Q56C43
LEDJMP: SOLDERJUMPERCLOSED; SOLDERJUMPER_CLOSEDWIRE
R1, R2: 10K; 0603-NO
R3, R4, R5, R6: 47K; 0603-NO
U2: HT16K33; SOP28_300MIL_SKINNY
U$1, U$2: FIDUCIAL; FIDUCIAL_1MM

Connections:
A0: A0.2, LED2.P$4, U2.P$23 (ROW2/A0)
A1: A1.2, LED2.P$8, LED2.P$9, U2.P$24 (ROW1/A1)
A2: A2.2, LED2.P$13, U2.P$25 (ROW0/A2)
GND: C1.2, CN1.3, CONN1.1 (GND), CONN1.MT1 (MT), CONN1.MT2 (MT), CONN2.1 (GND), CONN2.MT1 (MT), CONN2.MT2 (MT), D2.C, U2.P$1 (VSS)
unnamed: D1.C, R3.1, R4.1, R5.1
unnamed: D1.A, LED2.P$14, U2.P$2 (COM0/AD)
unnamed: LED2.P$11, U2.P$3 (COM1/KS0)
unnamed: LED2.P$7, U2.P$4 (COM2/KS1)
unnamed: LED2.P$10, U2.P$5 (COM3/KS2)
unnamed: LED2.P$6, U2.P$6 (COM4)
unnamed: A2.1, R5.2
unnamed: D2.A, R6.2
unnamed: LEDJMP.2, R6.1
unnamed: LED2.P$2, U2.P$22 (ROW3/K1)
unnamed: LED2.P$1, U2.P$21 (ROW4/K2)
unnamed: LED2.P$12, U2.P$20 (ROW5/K3)
unnamed: LED2.P$5, U2.P$19 (ROW6/K4)
unnamed: LED2.P$3, U2.P$18 (ROW7/K5)
unnamed: A1.1, R3.2
unnamed: A0.1, R4.2
SCL: CN1.1, CONN1.4 (SCL), CONN2.4 (SCL), R1.2, U2.P$26 (SCL)
SDA: CN1.2, CONN1.3 (SDA), CONN2.3 (SDA), R2.2, U2.P$27 (SDA)
VDD: C1.1, CN1.4, CONN1.2 (V+), CONN2.2 (V+), LEDJMP.1, R1.1, R2.1, U2.P$28 (VDD)

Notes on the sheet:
ON LED


Board: 2 copper layers, 50.0 x 26.7 mm, 25 parts (1 on the bottom side), 23 nets.

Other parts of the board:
U$3: ADAFRUIT_TEXT_20MM
U$5, U$6: STEMMAQT
U$7: PCBFEAT-REV-040

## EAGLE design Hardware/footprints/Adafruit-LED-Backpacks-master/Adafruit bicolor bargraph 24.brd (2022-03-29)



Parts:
A0, A1, A2: SOLDERJUMPERREFLOW_NOPASTE; SOLDERJUMPER_REFLOW_NOPASTE
C1: 10uF; 0805-NO
CN1: 1X4-CLEANBIG; 1X04-CLEANBIG
D1: 1N4148; SOD-323F
LED1, LED2: KWL-R1230CDUGB; SEGMENT_BICOL_BL-AR12Z3010
R1, R2: 10K; 0805-NO
R3, R4, R5: 47K; 0805-NO
U2: 28-SOIC; SOP28_300MIL
U$1, U$2: FIDUCIAL; FIDUCIAL_1MM
U$3, U$4: MOUNTINGHOLE2.5; MOUNTINGHOLE_2.5_PLATED

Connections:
A0: A0.2, LED1.4 (A5), U2.P$23 (ROW2/A0)
A1: A1.2, LED1.3 (A3), U2.P$24 (ROW1/A1)
A2: A2.2, LED1.2 (A1), U2.P$25 (ROW0/A2)
C0: D1.A, LED1.1 (C0), LED2.1 (C0), U2.P$2 (COM0/AD)
C1: LED1.6 (C1), LED2.6 (C1), U2.P$3 (COM1/KS0)
C2: LED1.7 (C2), LED2.7 (C2), U2.P$4 (COM2/KS1)
GND: C1.2, CN1.3, U2.P$1 (VSS)
unnamed: LED2.5 (A7), U2.P$18 (ROW7/K5)
unnamed: LED1.13 (A2), U2.P$17 (ROW8/K6)
unnamed: LED2.4 (A5), U2.P$19 (ROW6/K4)
unnamed: A2.1, R5.2
unnamed: D1.C, R3.1, R4.1, R5.1
unnamed: A1.1, R3.2
unnamed: A0.1, R4.2
unnamed: LED2.2 (A1), U2.P$21 (ROW4/K2)
unnamed: LED1.5 (A7), U2.P$22 (ROW3/K1)
unnamed: LED2.3 (A3), U2.P$20 (ROW5/K3)
unnamed: LED1.12 (A4), U2.P$16 (ROW9/K7)
R10: LED1.11 (A6), U2.P$15 (ROW10/K8)
R11: LED1.10 (A8), U2.P$14 (ROW11/K9)
R12: LED2.13 (A2), U2.P$13 (ROW12/K10)
R13: LED2.12 (A4), U2.P$12 (ROW13/K11)
R14: LED2.11 (A6), U2.P$11 (ROW14/K12)
R15: LED2.10 (A8), U2.P$10 (ROW15/K13/INT)
SCL: CN1.1, R1.2, U2.P$26 (SCL)
SDA: CN1.2, R2.2, U2.P$27 (SDA)
VDD: C1.1, CN1.4, R1.1, R2.1, U2.P$28 (VDD)



Board: 2 copper layers, 100.3 x 12.7 mm, 20 parts (4 on the bottom side), 27 nets.

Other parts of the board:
U$5: ADAFRUIT_TEXT_20MM
U$6: ADAFRUIT_3.5MM

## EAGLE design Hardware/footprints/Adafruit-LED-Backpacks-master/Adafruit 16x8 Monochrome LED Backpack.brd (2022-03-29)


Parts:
A0, A1, A2: SOLDERJUMPERREFLOW_NOPASTE; SOLDERJUMPER_REFLOW_NOPASTE
C1, C2, C3: 10uF; 0805-NO
CN1: 1X4-CLEANBIG; 1X04-CLEANBIG
D1: 1N4148; SOD-323F
LED1, LED2: DISP_SEGMENT_8X8_ROWCATHODEM12A881UR; SEGMENT_BL-M12A881UR
R1: 10K; R0805
R2, R3, R4, R5: 10K; 0805-NO
U2: 28-SOIC; SOP28_300MIL
U$1, U$2: FIDUCIAL; FIDUCIAL_1MM

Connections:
A0: A0.2, LED1.4 (A3), U2.P$23 (ROW2/A0)
A1: A1.2, LED1.3 (A2), U2.P$24 (ROW1/A1)
A2: A2.2, LED1.13 (A1), U2.P$25 (ROW0/A2)
GND: C1.2, C2.2, C3.2, CN1.3, U2.P$1 (VSS)
unnamed: LED1.5 (K8), LED2.5 (K8), U2.P$9 (COM7)
unnamed: LED1.2 (K7), LED2.2 (K7), U2.P$8 (COM6)
unnamed: LED1.7 (K6), LED2.7 (K6), U2.P$7 (COM5)
unnamed: LED1.1 (K5), LED2.1 (K5), U2.P$6 (COM4)
unnamed: LED1.12 (K4), LED2.12 (K4), U2.P$5 (COM3/KS2)
unnamed: LED1.8 (K3), LED2.8 (K3), U2.P$4 (COM2/KS1)
unnamed: LED1.14 (K2), LED2.14 (K2), U2.P$3 (COM1/KS0)
unnamed: D1.A, LED1.9 (K1), LED2.9 (K1), U2.P$2 (COM0/AD)
unnamed: A2.1, R5.2
unnamed: LED2.15 (A7), U2.P$11 (ROW14/K12)
unnamed: LED2.11 (A6), U2.P$12 (ROW13/K11)
unnamed: LED2.16 (A8), U2.P$10 (ROW15/K13/INT)
unnamed: D1.C, R3.1, R4.1, R5.1
unnamed: A1.1, R3.2
unnamed: A0.1, R4.2
unnamed: LED1.16 (A8), U2.P$18 (ROW7/K5)
unnamed: LED1.15 (A7), U2.P$19 (ROW6/K4)
unnamed: LED1.6 (A5), U2.P$21 (ROW4/K2)
unnamed: LED1.10 (A4), U2.P$22 (ROW3/K1)
unnamed: LED1.11 (A6), U2.P$20 (ROW5/K3)
unnamed: LED2.13 (A1), U2.P$17 (ROW8/K6)
unnamed: LED2.3 (A2), U2.P$16 (ROW9/K7)
unnamed: LED2.10 (A4), U2.P$14 (ROW11/K9)
unnamed: LED2.4 (A3), U2.P$15 (ROW10/K8)
unnamed: LED2.6 (A5), U2.P$13 (ROW12/K10)
SCL: CN1.1, R1.2, U2.P$26 (SCL)
SDA: CN1.2, R2.2, U2.P$27 (SDA)
VDD: C1.1, C2.1, C3.1, CN1.4, R1.1, R2.1, U2.P$28 (VDD)



Board: 2 copper layers, 72.4 x 32.0 mm, 20 parts (3 on the bottom side), 32 nets.

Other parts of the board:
U$3: ADAFRUIT_TEXT_20MM
U$4: ADAFRUIT_3.5MM

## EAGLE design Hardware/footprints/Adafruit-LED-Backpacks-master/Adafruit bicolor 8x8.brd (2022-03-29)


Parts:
A0, A1, A2: SOLDERJUMPERREFLOW_NOPASTE; SOLDERJUMPER_REFLOW_NOPASTE
C1: 10uF; C0805
CN1: 1X4-CLEANBIG; 1X04-CLEANBIG
D1: 1N4148; SOD-323F
LED2: DISP_SEGMENT_8X8_BICOLOR_ROWCATHODEMI2A883XX; SEGMENT_BICOL_BL-M12A883XX
R1, R2, R3, R4, R5: 10K; R0805
U2: 28-SOIC; SOP28_300MIL
U$1, U$2: FIDUCIAL; FIDUCIAL_1MM

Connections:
A0: A0.2, LED2.18 (A5), U2.P$23 (ROW2/A0)
A1: A1.2, LED2.21 (A3), U2.P$24 (ROW1/A1)
A2: A2.2, LED2.24 (A1), U2.P$25 (ROW0/A2)
GND: C1.2, CN1.3, U2.P$1 (VSS)
unnamed: LED2.12 (K8), U2.P$9 (COM7)
unnamed: LED2.9 (K7), U2.P$8 (COM6)
unnamed: LED2.6 (K6), U2.P$7 (COM5)
unnamed: LED2.3 (K5), U2.P$6 (COM4)
unnamed: LED2.13 (K4), U2.P$5 (COM3/KS2)
unnamed: LED2.16 (K3), U2.P$4 (COM2/KS1)
unnamed: LED2.19 (K2), U2.P$3 (COM1/KS0)
unnamed: D1.A, LED2.22 (K1), U2.P$2 (COM0/AD)
unnamed: A2.1, R5.2
unnamed: LED2.8 (A14), U2.P$11 (ROW14/K12)
unnamed: LED2.5 (A12), U2.P$12 (ROW13/K11)
unnamed: LED2.11 (A16), U2.P$10 (ROW15/K13/INT)
unnamed: D1.C, R3.1, R4.1, R5.1
unnamed: A1.1, R3.2
unnamed: A0.1, R4.2
unnamed: LED2.10 (A15), U2.P$18 (ROW7/K5)
unnamed: LED2.7 (A13), U2.P$19 (ROW6/K4)
unnamed: LED2.1 (A9), U2.P$21 (ROW4/K2)
unnamed: LED2.15 (A7), U2.P$22 (ROW3/K1)
unnamed: LED2.4 (A11), U2.P$20 (ROW5/K3)
unnamed: LED2.23 (A2), U2.P$17 (ROW8/K6)
unnamed: LED2.20 (A4), U2.P$16 (ROW9/K7)
unnamed: LED2.14 (A8), U2.P$14 (ROW11/K9)
unnamed: LED2.17 (A6), U2.P$15 (ROW10/K8)
unnamed: LED2.2 (A10), U2.P$13 (ROW12/K10)
SCL: CN1.1, R1.2, U2.P$26 (SCL)
SDA: CN1.2, R2.2, U2.P$27 (SDA)
VDD: C1.1, CN1.4, R1.1, R2.1, U2.P$28 (VDD)


Board: 2 copper layers, 40.6 x 33.1 mm, 16 parts (1 on the bottom side), 32 nets.

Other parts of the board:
U$3: ADAFRUIT_5MM

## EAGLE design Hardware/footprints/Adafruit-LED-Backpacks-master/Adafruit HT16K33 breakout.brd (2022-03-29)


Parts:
A0, A1, A2: SOLDERJUMPERREFLOW_NOPASTE; SOLDERJUMPER_REFLOW_NOPASTE
C1: 10uF; C0805
D1: 1N4148; SOD-323F
JP1, JP2: PINHD-1X14-CB; 1X14-CB
R1, R2: 10K; R0805
R3, R4, R5: 47K; R0805
U2: 28-SOIC; SOP28_300MIL
U$1, U$2, U$6: FIDUCIAL; FIDUCIAL_1MM
U$4, U$5: MOUNTINGHOLE2.5; MOUNTINGHOLE_2.5_PLATED

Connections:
A0: A0.2, JP1.9, U2.P$23 (ROW2/A0)
A1: A1.2, JP1.10, U2.P$24 (ROW1/A1)
A2: A2.2, JP1.11, U2.P$25 (ROW0/A2)
ANOD3: JP1.8, U2.P$22 (ROW3/K1)
ANOD4: JP1.7, U2.P$21 (ROW4/K2)
ANOD5: JP1.6, U2.P$20 (ROW5/K3)
ANOD6: JP1.5, U2.P$19 (ROW6/K4)
ANOD7: JP1.4, U2.P$18 (ROW7/K5)
ANOD8: JP1.3, U2.P$17 (ROW8/K6)
ANOD9: JP1.2, U2.P$16 (ROW9/K7)
ANOD10: JP1.1, U2.P$15 (ROW10/K8)
ANOD11: JP2.14, U2.P$14 (ROW11/K9)
ANOD12: JP2.13, U2.P$13 (ROW12/K10)
ANOD13: JP2.12, U2.P$12 (ROW13/K11)
ANOD14: JP2.11, U2.P$11 (ROW14/K12)
ANOD15: JP2.10, U2.P$10 (ROW15/K13/INT)
CATH0: D1.A, JP2.2, U2.P$2 (COM0/AD)
CATH1: JP2.3, U2.P$3 (COM1/KS0)
CATH2: JP2.4, U2.P$4 (COM2/KS1)
CATH3: JP2.5, U2.P$5 (COM3/KS2)
CATH4: JP2.6, U2.P$6 (COM4)
CATH5: JP2.7, U2.P$7 (COM5)
CATH6: JP2.8, U2.P$8 (COM6)
CATH7: JP2.9, U2.P$9 (COM7)
GND: C1.2, JP2.1, U2.P$1 (VSS)
unnamed: A2.1, R5.2
unnamed: D1.C, R3.1, R4.1, R5.1
unnamed: A1.1, R3.2
unnamed: A0.1, R4.2
SCL: JP1.12, R1.2, U2.P$26 (SCL)
SDA: JP1.13, R2.2, U2.P$27 (SDA)
VDD: C1.1, JP1.14, R1.1, R2.1, U2.P$28 (VDD)


Board: 2 copper layers, 20.3 x 35.6 mm, 20 parts (1 on the bottom side), 32 nets.

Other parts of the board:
U$3: ADAFRUIT_3.5MM
U$7: ADAFRUIT_5MM

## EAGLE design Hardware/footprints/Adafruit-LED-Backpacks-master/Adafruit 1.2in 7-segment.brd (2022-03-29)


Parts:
A0, A1, A2: SOLDERJUMPERREFLOW_NOPASTE; SOLDERJUMPER_REFLOW_NOPASTE
C1, C2, C3: 10uF; C0805K
D1: 1N4148; SOD-323F
JP1: HEADER-1X576MIL; 1X05_ROUND_76
LED1: BL-Q120X-41; SEGMENT_BL-Q120A
R1, R2: 10K; R0805
R3, R4, R5: 47K; R0805
U2: HT16K33_SOP28; SOP28_300MIL
U$1, U$2: FIDUCIAL; FIDUCIAL_1MM

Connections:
A0: A0.2, LED1.7, LED1.11, U2.P$23 (ROW2/A0)
A1: A1.2, LED1.6, LED1.12, U2.P$24 (ROW1/A1)
A2: A2.2, LED1.13, U2.P$25 (ROW0/A2)
GND: C1.2, C2.2, C3.2, JP1.3, U2.P$1 (VSS)
unnamed: D1.C, R3.1, R4.1, R5.1
unnamed: D1.A, LED1.1, U2.P$2 (COM0/AD)
unnamed: LED1.3, U2.P$3 (COM1/KS0)
unnamed: LED1.4, U2.P$5 (COM3/KS2)
unnamed: LED1.5, U2.P$6 (COM4)
unnamed: LED1.2, U2.P$4 (COM2/KS1)
unnamed: A2.1, R5.2
unnamed: JP1.5, R1.1, R2.1
unnamed: LED1.8, LED1.10, U2.P$22 (ROW3/K1)
unnamed: LED1.9, LED1.16, U2.P$21 (ROW4/K2)
unnamed: LED1.15, U2.P$20 (ROW5/K3)
unnamed: LED1.14, U2.P$19 (ROW6/K4)
unnamed: A1.1, R3.2
unnamed: A0.1, R4.2
SCL: JP1.1, R1.2, U2.P$26 (SCL)
SDA: JP1.2, R2.2, U2.P$27 (SDA)
VDD: C1.1, C2.1, C3.1, JP1.4, U2.P$28 (VDD)

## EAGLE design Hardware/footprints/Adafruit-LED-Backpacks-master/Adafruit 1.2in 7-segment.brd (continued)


Board: 2 copper layers, 119.6 x 50.8 mm, 18 parts (1 on the bottom side), 21 nets.

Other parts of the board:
U$3: ADAFRUIT_TEXT_30MM

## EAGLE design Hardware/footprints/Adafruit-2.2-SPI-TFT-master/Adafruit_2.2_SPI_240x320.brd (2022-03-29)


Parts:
C1, C2, C3: 10uF; _0805MP
CN1: MICROSD
FID1, FID2, FID3: FIDUCIAL""; FIDUCIAL_1MM
JP1: HEADER-1X1070MIL; 1X10_ROUND70
Q1: 2N2222; SOT23-WIDE
R1, R2, R3, R6: 10; _0805MP
R4: 1K; _0805MP
R5: 10K; _0805MP
U1: DISP_LCD_TM022HDH26; TM022HDH26_2.2IN_LCD
U2: RT9193-3.3; SOT23-5
U3: 74HC4050D; SOIC16
U$2, U$3, U$4, U$5: MOUNTINGHOLE2.5; MOUNTINGHOLE_2.5_PLATED

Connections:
3.3V: C2.1, C3.1, CN1.4 (SD_VDD), R5.2, U1.9 (VCC), U1.10 (LEDA), U2.5 (OUT), U3.1 (VCC)
BACKLIGHT: JP1.10, R4.1, R5.1
DC_3V: U1.4 (D/C), U3.15 (6Y)
DC_5V: JP1.3, U3.14 (6A)
GND: C1.2, C2.2, C3.2, CN1.6 (GND), CN1.MT1 (GND), CN1.MT2 (GND), JP1.1, Q1.2 (E), U1.1 (GND), U1.8 (GND), U2.2 (GND), U3.8 (GND)
LCDCS_3V: U1.5 (CS), U3.6 (3Y)
LCDCS_5V: JP1.6, U3.7 (3A)
LEDK: Q1.3 (C), R1.1, R2.1, R3.1, R6.1
MISO: CN1.7 (DATA_OUT), JP1.8, U1.7 (MISO)
MOSI_3V: CN1.3 (DATA_IN), U1.6 (MOSI), U3.4 (2Y)
MOSI_5V: JP1.7, U3.5 (2A)
unnamed: R1.2, U1.11 (LEDK)
unnamed: R2.2, U1.12 (LEDK)
unnamed: R3.2, U1.13 (LEDK)
unnamed: Q1.1 (B), R4.2
unnamed: R6.2, U1.14 (LEDK)
RESET_3V: U1.2 (RESET), U3.12 (5Y)
RESET_5V: JP1.4, U3.11 (5A)
SCLK_3V: CN1.5 (SCLK), U1.3 (SCK), U3.2 (1Y)
SCLK_5V: JP1.9, U3.3 (1A)
SDCS_3V: CN1.2 (CS), U3.10 (4Y)
SDCS_5V: JP1.5, U3.9 (4A)
VIN: C1.1, JP1.2, U2.1 (IN), U2.3 (EN)


Board: 2 copper layers, 40.6 x 66.0 mm, 23 parts (1 on the bottom side), 23 nets.

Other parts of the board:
U$20: ADAFRUIT_TEXT_30MM

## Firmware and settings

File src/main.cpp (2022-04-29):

#include <Arduino.h>
#include <Wire.h>
#include <SPI.h>
#include <AccelStepper.h>
#include <MultiStepper.h>
#include <QuadEncoder.h> // Teensy hardware quadrature decoder library
// "In-House" Libraries
#include <EncoderTach.h> // Our encoder RPM helper library
#include <TeensyLeadscrew.h> // Our main "virtual gearbox" backend lib
#include <elsControlPanel.h>
#include "Adafruit_LEDBackpack.h"
#include "Adafruit_MCP23X17.h"
#include "Bounce2mcp.h"

// BEGIN CONFIG SECTION
#define BACKEND_INTERRUPT_INTERVAL_MICROS 5 // How often (in microseconds) to call TeensyLeadscrew.cycle() ( which also calls AccelStepper.run() )

#define STEPPER_DRIVE_ENABLE_TEENSYPIN 5
#define STEPPER_DRIVE_STEP_TEENSYPIN 4
#define STEPPER_DRIVE_DIRECTION_TEENSYPIN 6
#define STEPPER_WARNING_SPEED 40000
#define STEPPER_MAX_SPEED 45000
#define STEPPER_MAX_ACCELERATION 500000
#define STEPPER_STEPS_PER_REV 2000

#define SPINDLE_ENCODER_PHASEA_TEENSYPIN 3
#define SPINDLE_ENCODER_PHASEB_TEENSYPIN 2
#define SPINDLE_TACH_SAMPLEPERIOD_MICROS 4000

// System Specs object for Backend
LatheHardwareInfo sysSpecs = {
  2.0, // encoderPulleyMultiplier : e.g. if the encoder runs at 2X spindle speed, make this 2
  8000, // encoderTicksPerRev
  STEPPER_STEPS_PER_REV, // stepsPerRev : usable steps per rev, including microsteps
  STEPPER_WARNING_SPEED, // warningStepRate : soft maximum for stepper motor (steps per sec), used for overspeed warning
  {20, tpi, leftHandThread_feedRight}, // leadscrewPitch : a Pitch struct with leadscrew specifications
};

/*
TFT Display Pin Info (3/21/2022)
SCK -> 13
MISO -> 12
MOSI -> 11
LCD_CS -> 10
SD_CS -> n/c
RESET -> 15
D/C -> 14
*/
#define TFT_SCK_TEENSYPIN 13
#define TFT_MISO_TEENSYPIN 12
#define TFT_MOSI_TEENSYPIN 11
#define TFT_DISPLAYCS_TEENSYPIN 10
#define TFT_RESET_TEENSYPIN 15
#define TFT_DC_TEENSYPIN 14

#define PANEL_ENCODER_PHASEA_TEENSYPIN 0
#define PANEL_ENCODER_PHASEB_TEENSYPIN 1

// END CONFIG

// Declare spindle encoder
// Hardware quadrature channel 1, phase A pin 3, phase B pin 2
QuadEncoder spindleEnc(1, SPINDLE_ENCODER_PHASEA_TEENSYPIN, SPINDLE_ENCODER_PHASEB_TEENSYPIN, 0);

// Declare Z axis stepper
AccelStepper zStepper(AccelStepper::DRIVER, STEPPER_DRIVE_STEP_TEENSYPIN, STEPPER_DRIVE_DIRECTION_TEENSYPIN);

// Backend Electronic Leadscrew "Gearbox" lib setup
TeensyLeadscrew els(spindleEnc, zStepper, sysSpecs, SPINDLE_TACH_SAMPLEPERIOD_MICROS);

// CONTROL PANEL HARDWARE OBJECTS

// TFT Display
Adafruit_ILI9341 tftObject(TFT_DISPLAYCS_TEENSYPIN, TFT_DC_TEENSYPIN, TFT_MOSI_TEENSYPIN, TFT_SCK_TEENSYPIN, TFT_RESET_TEENSYPIN, TFT_MISO_TEENSYPIN);

// Control Panel Encoder
// Hardware quadrature channel 2, phase A, phase B
QuadEncoder panelEnc(2, PANEL_ENCODER_PHASEA_TEENSYPIN, PANEL_ENCODER_PHASEB_TEENSYPIN, 0);

// Create control panel class
elsControlPanel cPanel(tftObject, panelEnc);

// Mechanism for ensuring the stepper's run() function gets called often enough
IntervalTimer backendTimer;

void backendISR() {
  els.cycle();
};

// @brief Helper function that checks the feed switch state, and updates the backend accordingly (except in backend overspeed condition)
void updateFeedSwitch() {
  if (els.leadscrewOverspeedAlarmActive == false) {
    if (cPanel.feedSwitch.currentState == neutral) {
      els.clutch.disengage();
    }
    else if (cPanel.feedSwitch.currentState == left_towardHeadstock) {
      els.clutch.engageForward();
    }
    else if (cPanel.feedSwitch.currentState == right_towardTailstock) {
      els.clutch.engageReverse();
    }
  }
}

// @brief Helper function for converting our Pitch structs to pretty human-readable strings
// @param Input pitch to be string-ified
// @returns e.g. "20TPI", "1.25mm", or "0.128" "
String generateDisplayablePitch(Pitch input) {
  String outputValue;

  String outputUnits;
  if (input.units == tpi){
    outputUnits = "TPI";
    outputValue = String(input.value, 0);
  }
  else if (input.units == mm){
    outputUnits = "mm";
    outputValue = String(input.value, 2);
  }
  else if (input.units == in_per_rev){
    outputUnits = "\"";
    outputValue = String(input.value, 3);
  }

  return outputValue + outputUnits;
}

void setup()
{
  // Initialize spindle encoder
  spindleEnc.setInitConfig();
  spindleEnc.init();

  // Initialize Z stepper
  zStepper.setMaxSpeed(STEPPER_MAX_SPEED);
  zStepper.setAcceleration(STEPPER_MAX_ACCELERATION);
  zStepper.setEnablePin(STEPPER_DRIVE_ENABLE_TEENSYPIN);

  // Initialize control panel hardware
  cPanel.init();

  // Initialize electronic leadscrew backend
  els.init();
  
  // Start the TFT splash screen
  cPanel.TFT_splashscreen();
  delay(2000);

  // Start the timer interrupt which calls els.cycle()
  // This "arms" the system
  backendTimer.begin(backendISR, BACKEND_INTERRUPT_INTERVAL_MICROS);
}

// Note that while this loop is handling input from the user, the backend is getting called with a timer interrupt every 5us
// (so any updates we make to the backend here take virtually immediate effect)
void loop()
{ 
  // STEP 1: HANDLE BUTTON PRESSES (UNITS, RAPIDS, MOTOR BRAKING SWITCH)
  cPanel.updateInputs();

  // Update motor braking setting (the cPanel.brakingSwitch.enableMotorBraking bool is updated by updateInputs() )
  els.gearbox.enableMotorBraking = cPanel.brakingSwitch.enableMotorBraking;

  /*
  Button Assignments:
  F1 = Units Toggle (TPI/mm per rev/inches per rev)
  F2 = Rapid Toggle
  F3 = Unused
  */
  
  // Handle F1, units button
  if (cPanel.function1Btn.debouncedButton.fell()){
    // Toggle units
    // The order we use is TPI/mm/in_per_rev
    if (els.gearbox.configuredPitch.units == tpi){
      els.gearbox.configuredPitch.units = mm;
      // Default to 1.0mm pitch
      els.gearbox.configuredPitch.value = 1.0;
    }
    else if (els.gearbox.configuredPitch.units == mm) {
      els.gearbox.configuredPitch.units = in_per_rev;
      // Default to 0.001 feed pitch
      els.gearbox.configuredPitch.value = 0.001;
    }
    else if (els.gearbox.configuredPitch.units == in_per_rev){
      els.gearbox.configuredPitch.units = tpi;
      // Default to 20tpi pitch;
      els.gearbox.configuredPitch.value = 20;
    }
  }

  // Handle F2, Rapid Toggle
  if (cPanel.function2Btn.debouncedButton.fell()) {
    // WIP
  }

  // STEP 2: POLL FEED SWITCH AND UPDATE BACKEND
  updateFeedSwitch();

  // STEP 3: CHECK FOR PANEL ENCODER MOVEMENT (PITCH ADJUSTMENT)
  int encClicks = (cPanel.encoder.read() / 4);
  if (encClicks != 0) {
    cPanel.encoder.write(0);

    // The increment amount of the encoder changes depending on the unit
    float increment;
    if (els.gearbox.configuredPitch.units == tpi) {
      increment = 1.0;
    }
    else if (els.gearbox.configuredPitch.units == mm) {
      increment = 0.05;
    }
    else if (els.gearbox.configuredPitch.units == in_per_rev) {
      increment = 0.001;
    }

    // Increment the configured pitch according to the encoder movement
    float change = increment * (float)encClicks;
    if ((els.gearbox.configuredPitch.value + change) < 0) {
      els.gearbox.configuredPitch.value = 0; // Prevent negative pitches
    }
    else {
      els.gearbox.configuredPitch.value = els.gearbox.configuredPitch.value + change;
    }
  }

  // STEP 4: POLL FEED SWITCH AND UPDATE BACKEND
  updateFeedSwitch();
  
  // STEP 5: GET SPINDLE RPM FROM BACKEND, WRITE TO ALPHANUMERIC DISPLAY
  int spindleRPM = els.spindleTach.getRPM();
  cPanel.alphanum_writeRPM(spindleRPM);

  // Handle overspeed indicator
  if (els.zStepper.speed() > (sysSpecs.warningStepRate)) {
    cPanel.writeOverspeedLED(true);
  }
  else {
    cPanel.writeOverspeedLED(false);
  }

  // STEP 6: UPDATE TFT WITH CURRENT PITCH SETTINGS

  // Get the pitch in nice pretty format ignoring direction (e.g. "20TPI" or "1.75mm")
  String pitch_displayable = generateDisplayablePitch(els.gearbox.configuredPitch);
  cPanel.TFT_writeGearboxInfo("", pitch_displayable, "TPI/mm/in", "", "");

  // STEP 7: POLL FEED SWITCH AND UPDATE BACKEND
  updateFeedSwitch();
}

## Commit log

2022-01-24 Reorganizing, adding beginning of KiCad work
    [Electroturn.kicad_pcb, Electroturn.kicad_sch]
2022-01-26 Converting Teensy library to newer format
2022-01-26 Improving Teensy 4.0 symbol
    [Electroturn.kicad_sch]
2022-01-26 Setting up Arduino project, testing encoder in software
    [Electroturn.kicad_sch]
2022-02-06 Initial encoder and stepper test code
2022-02-07 Initial layout ideas, spindle speed computation
2022-02-13 Adding 8 pin aviation connector to KiCad schematic
    [Electroturn.kicad_sch]
2022-02-17 Framework of code for inital development
2022-02-21 Roughing out modes, power feed code
2022-02-27 Starting to build out backend leadscrew library
2022-03-04 Gear ratio computation, changed function types
2022-03-16 Got referencing issues fixed, backend has access to hardware now!
    [main.cpp]
2022-03-17 Beth Annes kicad work part 1
    [Electroturn.kicad_sch, KiCAD.kicad_pcb, KiCAD.kicad_sch]
2022-03-17 Beth Annes work deleting unnecessary folder
    [KiCAD.kicad_pcb, KiCAD.kicad_sch]
2022-03-17 Adjusting control panel display schematic
    [Electroturn.kicad_sch]
2022-03-21 Added LED backpack library and removed separate 7seg display libraries
2022-03-21 Adding missing RST pin for TFT display in KiCad schematic
    [Electroturn.kicad_sch]
2022-03-21 Renaming/restructuring control panel lib
    This is a skeleton of the control panel lib, and I think the display objects (for the TFT and the alphanum) are both created correctly now. Haven't tested on actual hardware yet.
    [main.cpp]
2022-03-23 Adding pulley multiplier to leadscrew backend
2022-03-24 Text Display fucntional, added I2C lib but still wip for alphanueric
2022-03-24 Work on virtual clutch (semi successful) This works, with some error, but the error seems to be speed dependent. Not sure if this is programming error (more "lost" data with higher speeds) or error i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
    [main.cpp]
2022-03-25 Added splashscreen, fixed format of display
    [main.cpp]
2022-03-26 Removing unnecessary i2c lib
2022-03-27 New branch for pcb work
    [Adafruit 0.54 Alphanumeric v0.1.brd, Adafruit 0.54 Alphanumeric v0.1.sch, Adafruit 0.56 7-Segment QT.brd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]
2022-03-27 Something like a pcb?
    [Electroturn.kicad_pcb]
2022-03-28 Adding 3D models, improving footprints for Teensy and Gecko, adding screw terminals to schematic
    [Electroturn.kicad_pcb, Electroturn.kicad_sch]
2022-03-29 Adding MCP23017 (i2c IO chip) to schematic, other housekeeping
    [Electroturn.kicad_sch]
2022-03-29 Consolidating most things into buses on schematic
    [Electroturn.kicad_sch]
2022-03-29 Fixed formating issues for TFT and changed TFT test code
    [main.cpp]
2022-03-29 Edited comments, changed argumens of LED function
2022-03-30 Temporarily reversing system for sync test
    [main.cpp]
2022-03-30 Working test code using absolute coordinates, not sure why relative motion doesn't work right
    [main.cpp]
2022-03-30 Fixing mislabeled interrupt pins
    [Electroturn.kicad_sch]
2022-03-30 Fixing R values in panel encoder voltage divider
    [Electroturn.kicad_sch]
2022-03-30 Adding proper GitIgnore for KiCAD
2022-03-30 Removing newly ignored KiCAD cache files
2022-03-30 Adding gitignore for KiCAD
2022-03-30 Removing newly ignored KiCAD files
2022-03-30 Reorganizing KiCAD repo, fixing path issues
    I tidied up the folder structure, and also went in and relinked all the footprints/symbols using the correct new paths. Should work across any system now. Also linked the appropriate 3D models for the Teensy and Gecko.
    I updated the PCB to include all these new changes from the footprints/schematic, and in doing so it pretty much destroyed what Karson had...sorry Karson
    [Adafruit 0.54 Alphanumeric v0.1.brd, Adafruit 0.54 Alphanumeric v0.1.sch, Adafruit 0.56 7-Segment QT.brd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]
2022-03-31 Removing old leftovers from TeensyLeadscrew
2022-03-31 Changed name for buttons
    [Electroturn.kicad_sch]
2022-03-31 Adding connection to schematic, test code for buttons
    [Electroturn.kicad_sch]
2022-04-02 Removing KiCad edit commit: "Changed name for buttons"
    This reverts commit c135a4e2cf57f768540b1a317894a2067f308fdb.
    [Electroturn.kicad_sch]
2022-04-02 Reverting change to KiCad schematic to prevent merge issues
    [Electroturn.kicad_sch]
2022-04-02 Moving gearbox info into struct, tidying
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2022-04-03 Added button functions, changed a few function args
2022-04-03 Buttons done minus units
2022-04-03 Beth Anne's footprint designs
2022-04-03 Adding tolerance math to clutch locking
    [main.cpp]
2022-04-03 Removing tolerance math (unforeseen issues need lots of careful testing)
    [main.cpp]
2022-04-04 Adding encoder filter circuit, assuming 5V operation (subject to change)
    [Electroturn.kicad_sch]
2022-04-04 Fixing Rotarty Switch Footprint
2022-04-04 Adding pin numbers to adafruit TFT symbol
    [Electroturn.kicad_sch]
2022-04-04 Adding 3D model and footprint for TFT
    [AdafruitTFT_withHeaders_full3Dmodel.step, Adafruit_2.2_SPI_240x320.kicad_pcb, Adafruit_2.2_SPI_240x320.kicad_sch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]
2022-04-04 Adding alphanumeric display footprint
    [Adafruit 0.54 Alphanumeric v0.1.kicad_pcb, Adafruit 0.54 Alphanumeric v0.1.kicad_sch, Adafruit 0.54 Alphanumeric v0.1.step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]
2022-04-04 More footprint work
    [Electroturn.kicad_sch]
2022-04-04 Debouncing stuff?, fixed display
    [main.cpp]
2022-04-05 Adding footprint for SPDT feed switch from ECE dept
2022-04-05 Quick Fix: swapping panel encoder to 3.3V
    [Electroturn.kicad_sch]
2022-04-05 Fixing broken symbol links from merge
    [Electroturn.kicad_sch]
2022-04-05 Quick fixes: schematic housekeeping
    [Electroturn.kicad_sch]
2022-04-05 Initial PCB work
    [Electroturn.kicad_pcb, Electroturn.kicad_sch]
2022-04-05 Adding symbol and footprint for 5V regulator
2022-04-05 Adding 5V regulator to schematic
    [Electroturn.kicad_sch]
2022-04-05 Adding 1x2 screw terminal footprint, assigning 3D models
2022-04-05 Footprint housekeeping, updating PCB components
    [Electroturn.kicad_pcb, Electroturn.kicad_sch]
2022-04-05 Adding design rules for PCB milling
    Adding design rules based on Bantam's Othermill (the Haas is probably way more accurate than that, but I'm taking this conservatively)
    [Electroturn.kicad_pcb]
2022-04-05 Locking major control panel UI components
    [Electroturn.kicad_pcb]
2022-04-05 Revert "Initial PCB work" to prevent KiCad merge hell
    This reverts commit 830c4b3218d3f5d7a4b251521e18afe8c7a9bcf8.
    [Electroturn.kicad_pcb, Electroturn.kicad_sch]
2022-04-05 Importing corrected footprint for rotary switch
2022-04-05 Adding 3D model for rotary switch
2022-04-05 Updating rotary switch footprint on PCB
    [Electroturn.kicad_pcb]
2022-04-05 Some placement work
    [Electroturn.kicad_pcb, Electroturn.kicad_sch]
2022-04-05 correcting mislabeled function button
    [Electroturn.kicad_pcb]
2022-04-05 Initial placements
    [Electroturn.kicad_pcb]
2022-04-05 Adding net classes for PCB traces
    [Electroturn.kicad_pcb]
2022-04-05 Fixing schematic parity issues with PCB footprints
    [Electroturn.kicad_pcb, Electroturn.kicad_sch]
2022-04-05 PCB is routed
    [Electroturn.kicad_pcb]
2022-04-05 Adding mounting holes, starting to generate gerbers
    [Electroturn-B_Cu.gbl, Electroturn-B_Mask.gbs, Electroturn-B_Silkscreen.gbo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]
2022-04-06 Adding mounting holes and re-exporting Gerbers and STEP
    [Electroturn-B_Cu.gbl, Electroturn-B_Mask.gbs, Electroturn-B_Silkscreen.gbo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]
2022-04-06 Adding MCP23017 button mappings to enum
2022-04-08 Temporary feed switch code for testing on lathe
2022-04-09 Commenting TeensyLeadscrew and clutch class
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2022-04-11 Cleaning up unbuildable code in main.cpp
    [Electroturn.kicad_pcb]
2022-04-13 Setup basic work flow, changed TFT layout, debounce buttons stuff
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2022-04-18 Cleaning up typos, adding test code for UI inputs, all buttons and switches working
2022-04-18 Beginning to add business logic, fixing error in tachometer math
    [main.cpp]
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2022-04-23 Adjusting display font size, fixing encoder noise issues
    [main.cpp]
2022-04-24 Removing non-working attempt at making motor braking smarter

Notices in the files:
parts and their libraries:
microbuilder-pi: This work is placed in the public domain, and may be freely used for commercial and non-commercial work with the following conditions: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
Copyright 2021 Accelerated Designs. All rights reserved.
